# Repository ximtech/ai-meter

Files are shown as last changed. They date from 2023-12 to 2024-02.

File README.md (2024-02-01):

# AI-Meter project

#### Inspired with a project: [AI-on-the-edge-device](https://github.com/jomjol/AI-on-the-edge-device)

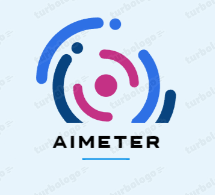
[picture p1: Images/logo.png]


## Overview

This project is a try to create a unified platform that can receive and 
handle telemetry data such as water, gas, and electricity meter readings autonomously and in an easily configurable way.

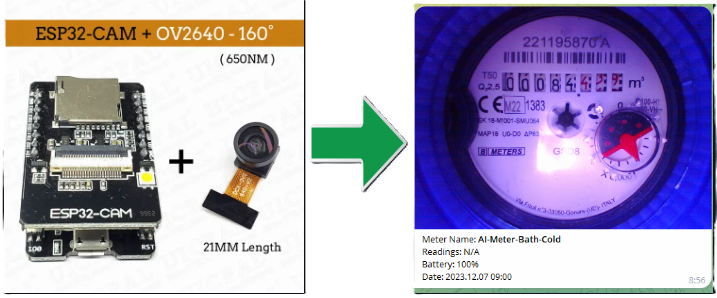
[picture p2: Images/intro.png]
esp32-cam


## Features

- Easy configuration and setup
- Modern Web View using [Bootstrap 5](https://getbootstrap.com/docs/5.0/getting-started/introduction/)
- Dynamic web pages with [Jquery](https://jquery.com/) and [CSP](https://github.com/ximtech/CSP) templates
- Telegram integration. Receive meter reading with bot support
- Flexible cron job configuration
- Timezone auto resolving using Geo IP service. Also timezone can be setup from embedded DB
- Using an advanced [Date-time](https://github.com/ximtech/GlobalDateTime) library that supports timezones and DST rules
- Embedded database(Sqlite) that stores timezones and DST rules
- Self-sufficient file server with all containing images, icons, css, js, fonts etc
- Long autonomous work from inner battery (up to 1 year)

## TODO

- Create custom ESP32 cam board with low current consumption ⬜
- File system control in an admin panel ✅
- Tensorflow Lite integration and image recognition ⬜
- Captive portal instead hardcoded IP for web view ⬜
- Wi-Fi password and other sensitive data asymmetric encryption ✅

## Table of Contents

- [How it works](#how-it-works)
  * [First time setup](#first-time-setup)
  * [Workflow](#workflow)
  * [Setup as needed](#setup-as-needed)
- [Software](#software)
  - [SD Card](#sd-card)
  - [Build](#build)
  - [Prerequisites](#prerequisites)
- [Hardware](#hardware)
  * [Adapter board](#adapter-board)
  * [Design notes](#design-notes)
  * [Power supply](#power-supply)
  * [Batteries](#batteries)
  * [External antenna](#external-antenna)
  * [Wiring](#wiring)
- [Housing](#housing)
  - [Water meter case](#water-meter-case)
    - [Assembly](#water-meter-case)
- [Geo IP](#geo-ip)
- [Telegram chat bot](#telegram-chat-bot)
- [Admin page](#admin-page)

## How it works

### First time setup

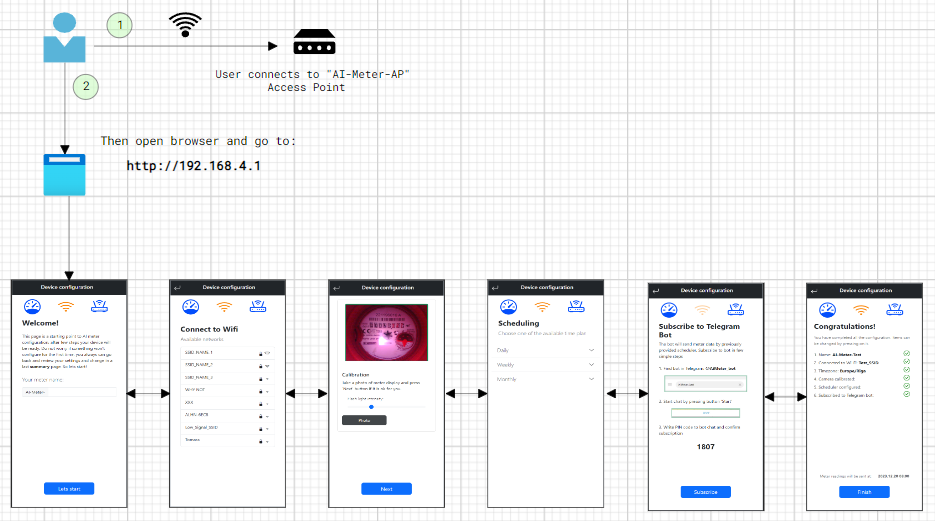
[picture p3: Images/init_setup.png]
init-setup


When `wlan.properties` is empty then a device enables access point witch user can connect and moving step by step set all required parameters.
At the last `summary.csp` page, all steps have been validated and viewed. Also, each item in the list can be changed by clicking on it.
If all ok, then 'Finish' button will be displayed, and after pressing on it, the device enables cron and go to the deep sleep. 

### Workflow

workflow

The device takes photos of a meter at a defined cron scheduler.
After initial setup, the device calculates how long need sleep;
then after wakeup it verifies if it's a time and if all ok, then starting job execution.

### Setup as needed

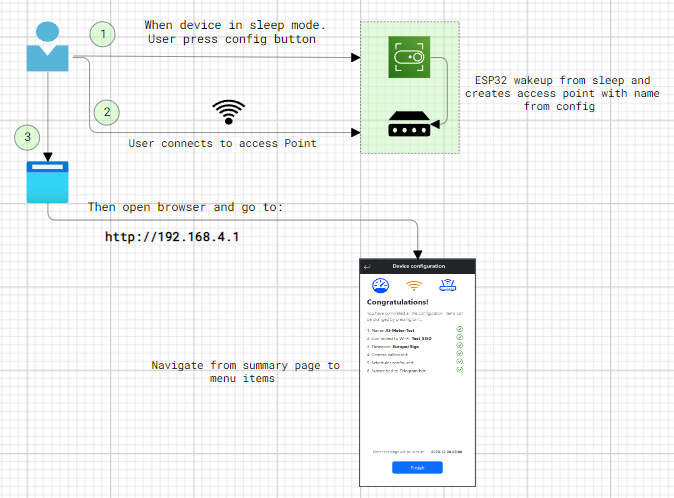
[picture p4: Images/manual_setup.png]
manual-setup


When there is a need to reconfigure or update the device while it is in sleep mode, press config button.
Then wait when led starts blinking and search Wi-Fi access point with name assigned from initial setup.

## Software

## SD Card

The software expects an SD card prepared with certain directory and file structure to work properly.
Card content can be found in `ai-meter -> MCU -> sd-card`.
Just copy all content in properly formatted(see notes) SD card.
As a result in most top directory should look like this:<br/>
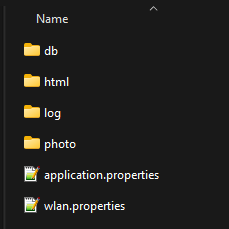
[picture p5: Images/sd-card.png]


#### Notes

- Due to the constrained GPIO availability for components such as OV2640, Flash-Light, PSRAM, and SD card,
  the communication mode with the SD card is confined to 1-line SD-Mode.
  This limitation can cause problems with high-capacity SD cards (64GB, and sometimes 32GB),
  as well as inexpensive, unbranded SD cards.
- Following setting they are necessary for formatting the SD-card: SINGLE PARTITION, MBR, FAT32—32K. NOT exFAT

#### Format example

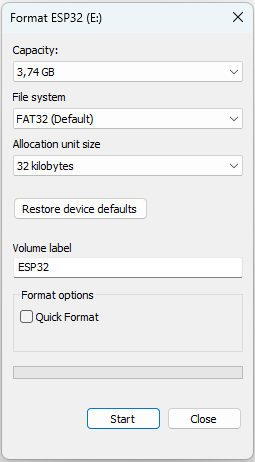
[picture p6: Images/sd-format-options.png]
format-example


### Build

### Prerequisites

- Esp-idf and Platformio should be already installed

The most common way to get firmware is to build it from sources:
- Clone this repository and open `MCU` directory as a project:
- In `Visual Studio Code` -> Open Folder -> MCU
- Then run PlatformIO build: <br/>
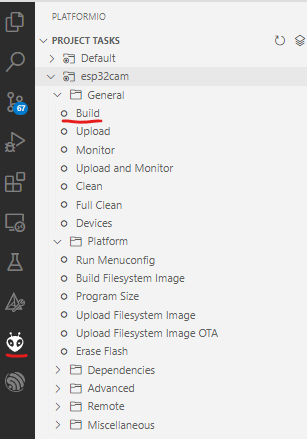
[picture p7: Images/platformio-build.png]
platformio-build
  
- If all ok, plug the device:<br/>
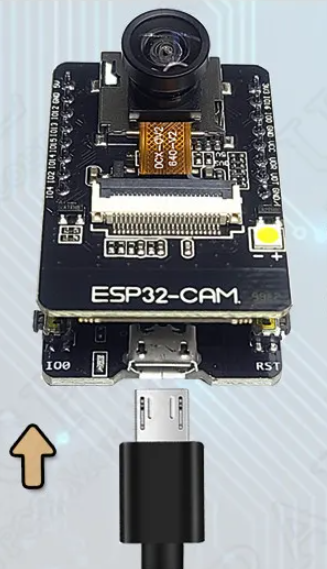
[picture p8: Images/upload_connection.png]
upload_connection_2
  
- Then upload firmware
- When the process is finished, turn on the monitor to see log outputs:<br/>
  battery
- By default, console log enabled and `debug` level is set (can be changed in config)

## Hardware

- ESP32 CAM Camera Module Kit
- OV2640 Camera Module, 120 or 160 Degree, 2MP
- External 4 or 8 MB PSRAM
- Micro SD card from 2 to 8 GB
- USB download board
- Battery power supply, adapter board (see below)

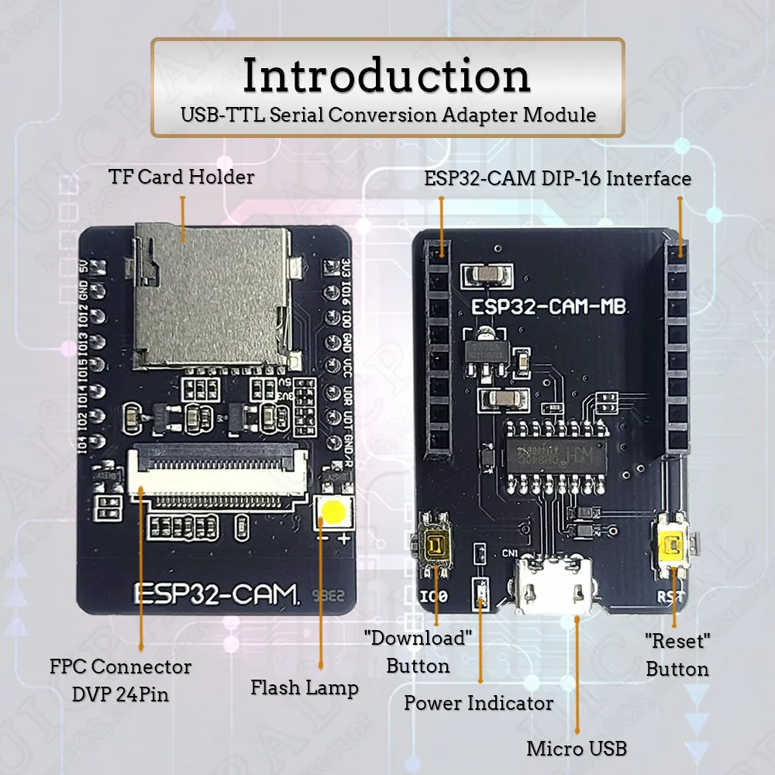
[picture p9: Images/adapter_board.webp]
adapter-board


### Adapter board

ESP32 module kit does not support to be powered from batteries by default.
So to use the device autonomously without an external power supply, there is a need to update `USB download board`
to a custom solution.
The directory `esp32-cam-shield` is an Altium project that contains all sources for this board.

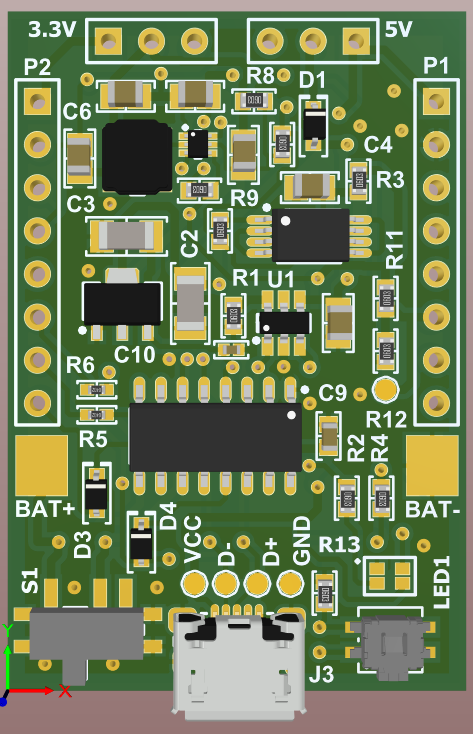
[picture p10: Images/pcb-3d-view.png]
pcb-3d-view


The PCB contains: 
- Almost all parts from the original `USB download board`
- Li-ion charger
- Battery protection
- Step-down converter

Altium project also already contains prepared fabrication files (gerber files, NC drill etc.) in one archive `esp32-cam-shield.rar`
Just place it, for example, in jlcpcb quote as follows:

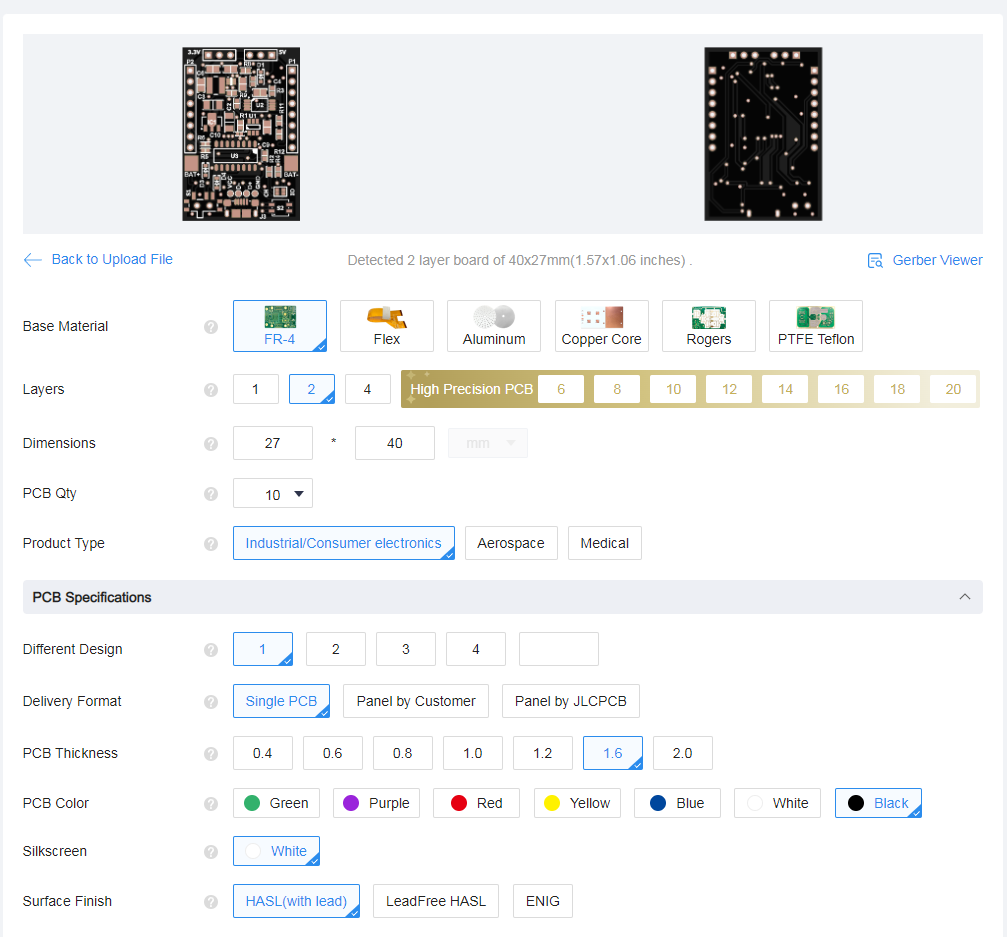
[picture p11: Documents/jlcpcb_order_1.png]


More info (schematic, PCB, BOM etc.) in `esp32-cam-shield` project

### Design notes

- For current housing, push button and switch should be used as follows:<br/>
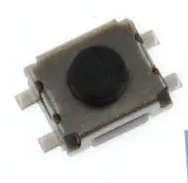
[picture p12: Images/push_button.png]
push-button
<br/>

#### 3x4x2 mm SMD Switch 4 Pin Micro Switch Push Button

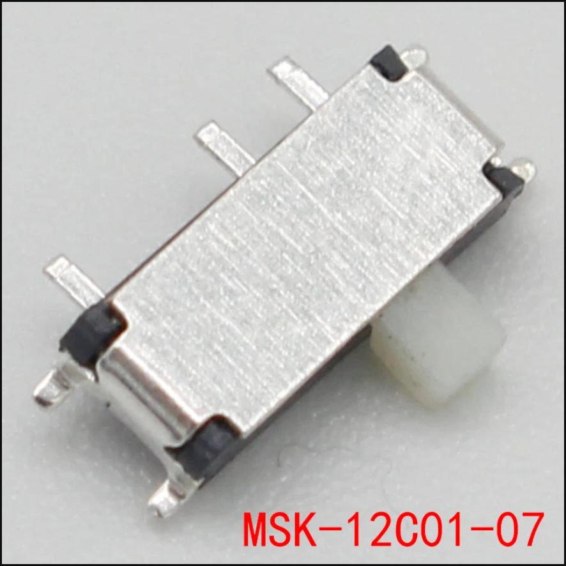
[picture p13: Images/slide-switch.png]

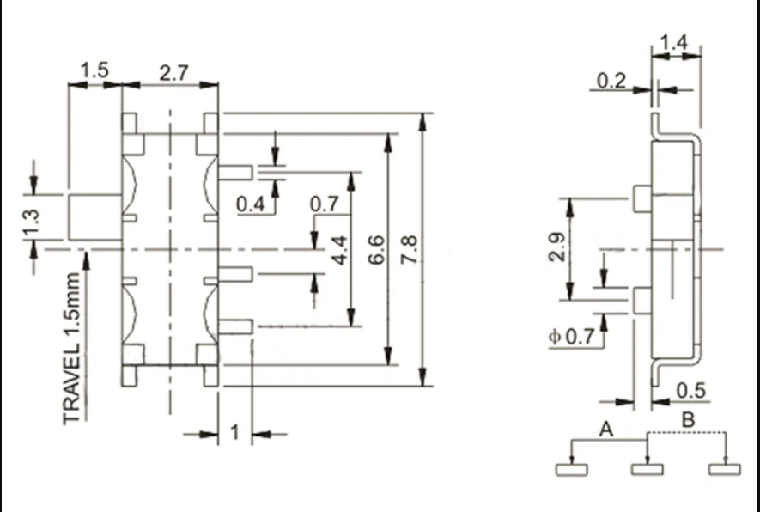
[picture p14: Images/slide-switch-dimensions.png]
<br/>

#### Mini Slide Switch On-OFF 2 positions, 7 pins

### Power supply

With the adapter board, there are two types of power supply available: 
- External 5V via USB and should support minimum 500mA. Solder two pins together to switch external power supply:<br/>
push-button
- From inner li-ion battery, also can be charged from USB. Solder this pins:<br/>
push-button

### Batteries

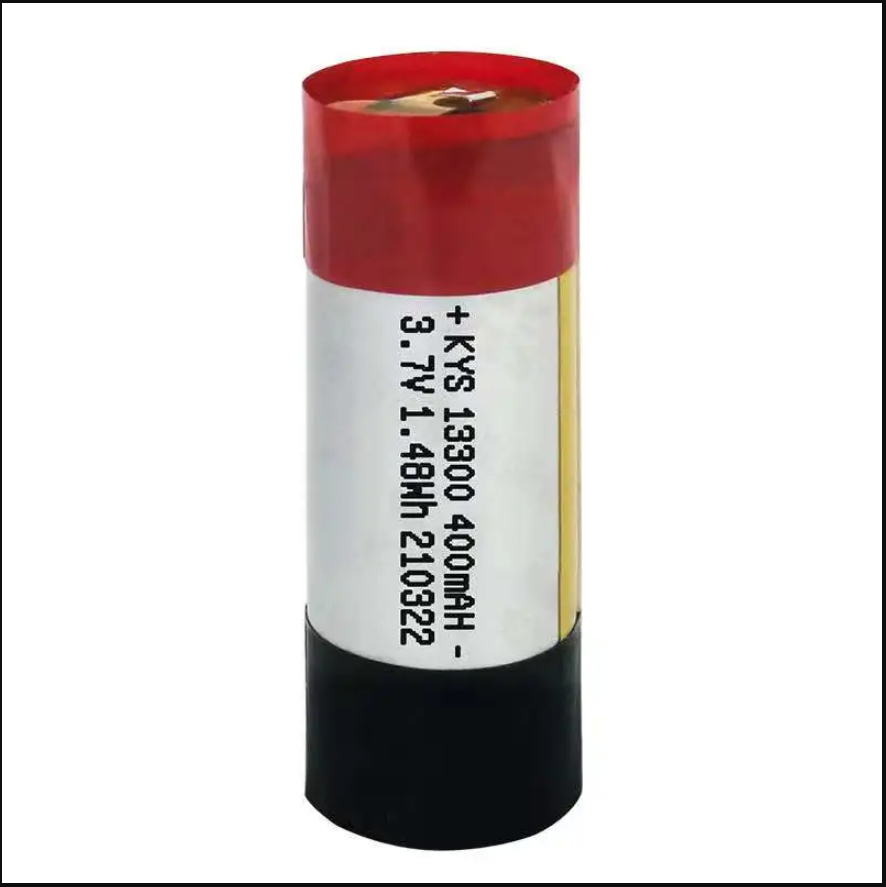
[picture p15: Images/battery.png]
battery


- Type: 13300
- Size: 13mm x 30mm
- Li-ion 3.7V 400mAh
- Count: 3

Such batteries are widely used at one-time vapes and can be extracted from used electronic smoke.

### External antenna

***Optional***, but highly recommended to use external antenna,
because using an external antenna can solve problems related to connectivity problems and speed up data transmission.

- Take a look at your board to see if it is set to use the on-board antenna or the IPEX connector.<br/>
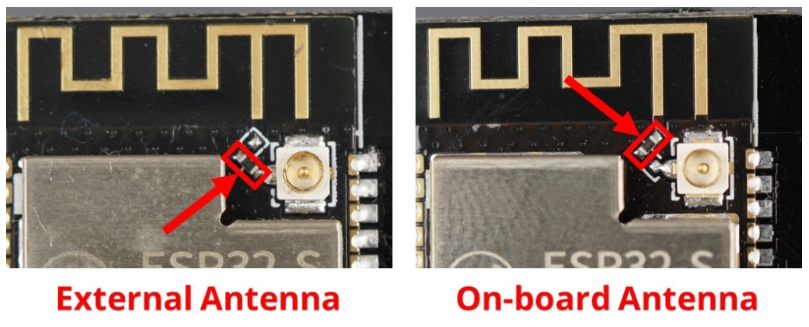
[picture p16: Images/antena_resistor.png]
antenna-resistor

- To enable or disable the on-board antenna, you just need to unsolder that resistor and solder it in the desired configuration. 
You can also drop some solder to connect those points (you don’t necessarily need to add the resistor as long as the pads are connected)
- Next, there is a need to connect flexible patch antenna with cable length about 10 cm:<br/>
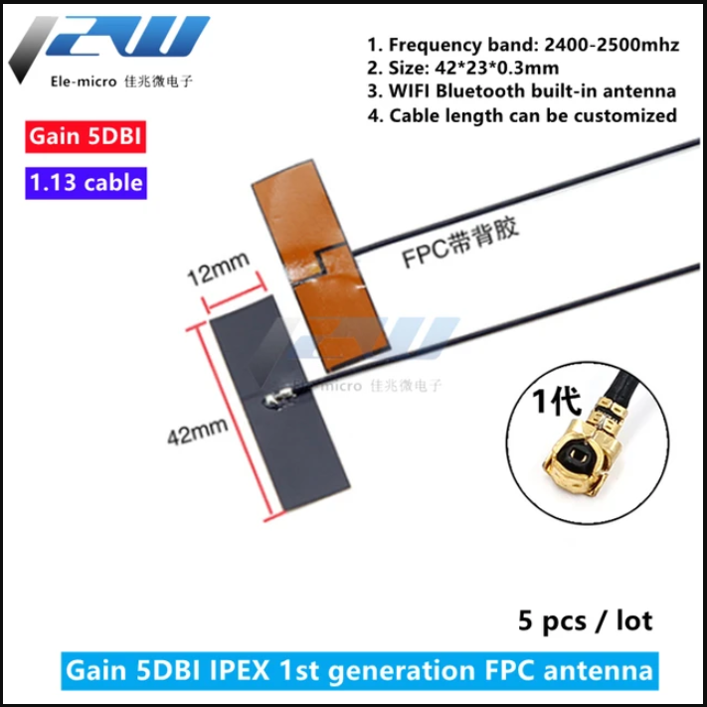
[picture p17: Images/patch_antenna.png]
antenna-resistor


## Wiring

After soldering all together, it should look like on a photo:<br/>
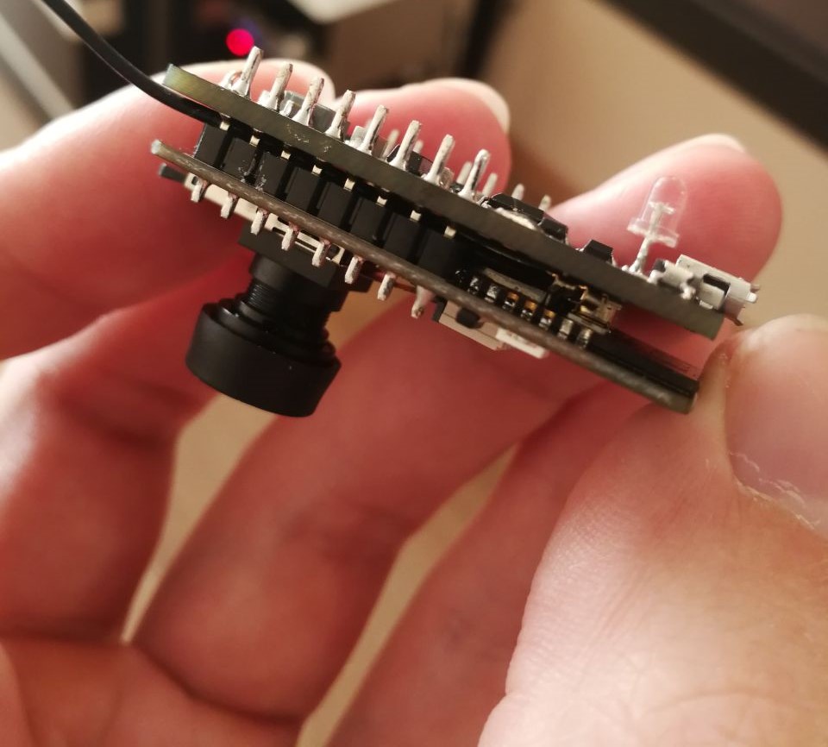
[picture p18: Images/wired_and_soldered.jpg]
wired-and-soldered
<br/>

## Housing

---

## Water meter case

The `3D Model` directory contains `SolidWorks` source models for 3D printing.
All that needs to be printed for a single device from `water` directory:
- 1x -`Base.SLDASM` -> ***Resolution: 0.2, Walls: 2–3, Infill: 20%+, Supports: Yes, Filament material: PLA***
- 3x -`Battery_Lid.SLDASM` -> ***Resolution: 0.2, Walls: 2, Infill: 100%, Supports: No, Filament material: PLA***
- 1x -`Button.SLDASM` -> ***Resolution: 0.12, Walls: 2, Infill: 100%, Supports: No, Filament material: PLA***
- 1x -`Flash_Reflector.SLDASM` -> ***Resolution: 0.12, Walls: 2, Infill: 50%+, Supports: No, Filament material: Transparent PLA***
- 1x -`Led_Pipe.SLDASM` -> ***Resolution: 0.12, Walls: 2, Infill: 100%, Supports: No, Filament material: Transparent PLA***
- 1x -`Holder.SLDASM` -> ***Resolution: 0.2, Walls: 2–3, Infill: 20%+, Supports: No, Filament material: PLA***
- 1x -`Lid.SLDASM` -> ***Resolution: 0.2, Walls: 2–3, Infill: 20%+, Supports: No, Filament material: PLA***
- 1x -`On_Off_Switch.SLDASM` -> ***Resolution: 0.12, Walls: 2, Infill: 100%, Supports: No, Filament material: PLA***

## Assembly

### Prerequisites

- 4x - ***M3 Brass inserts: 5–8mm tall***
- 20x - ***3x2mm Round neodymium magnets***<br/>
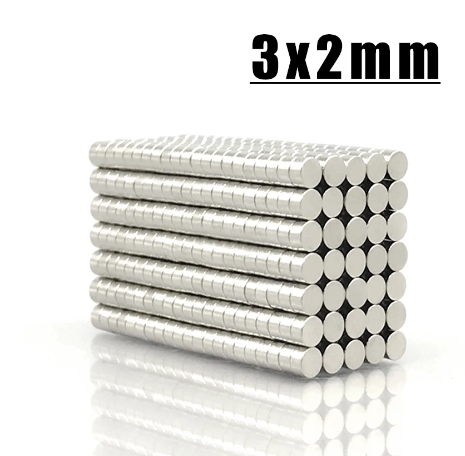
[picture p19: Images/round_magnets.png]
round-magnets


### 1. Melt brass inserts into the base holes

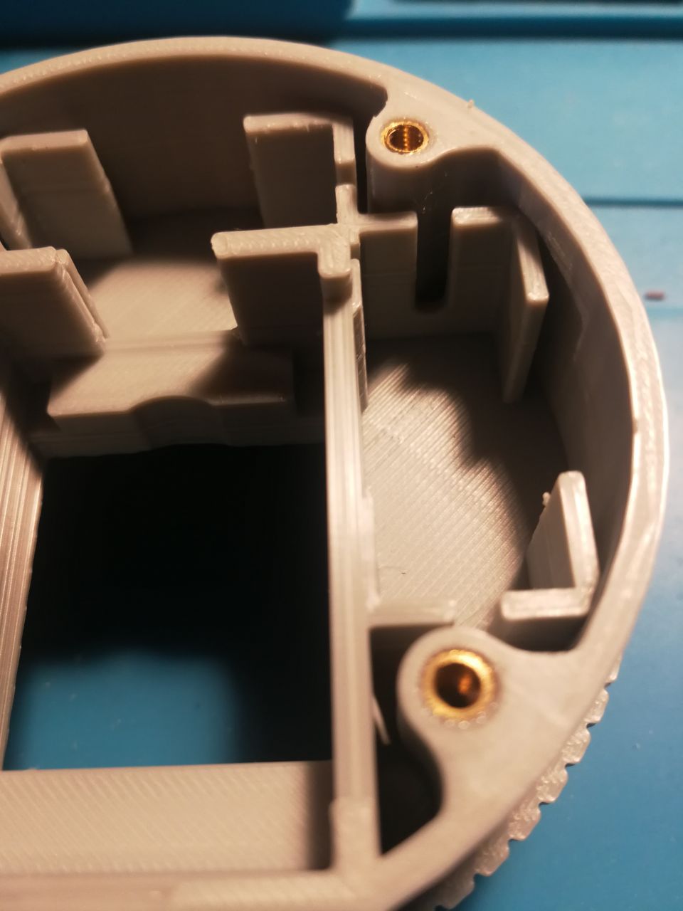
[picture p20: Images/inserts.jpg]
inserts


### 2. Insert contact magnets to base and holder

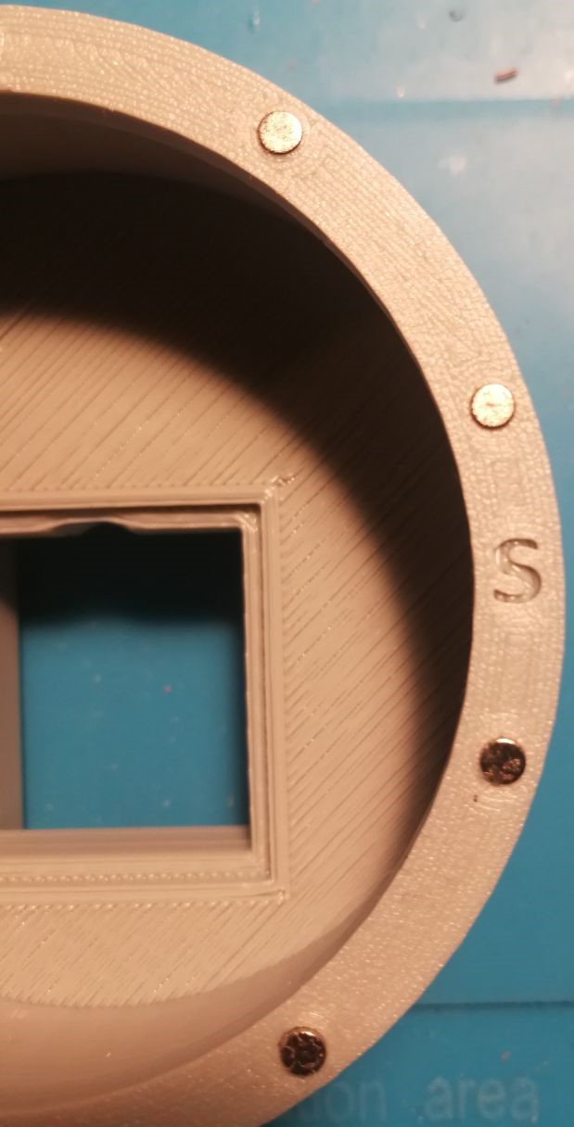
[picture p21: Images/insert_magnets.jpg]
magnets


***Note:*** Place magnets according to a letter on the case: `S` -> indicating that the south pole should be facing upward. 

### 3. Place reflector

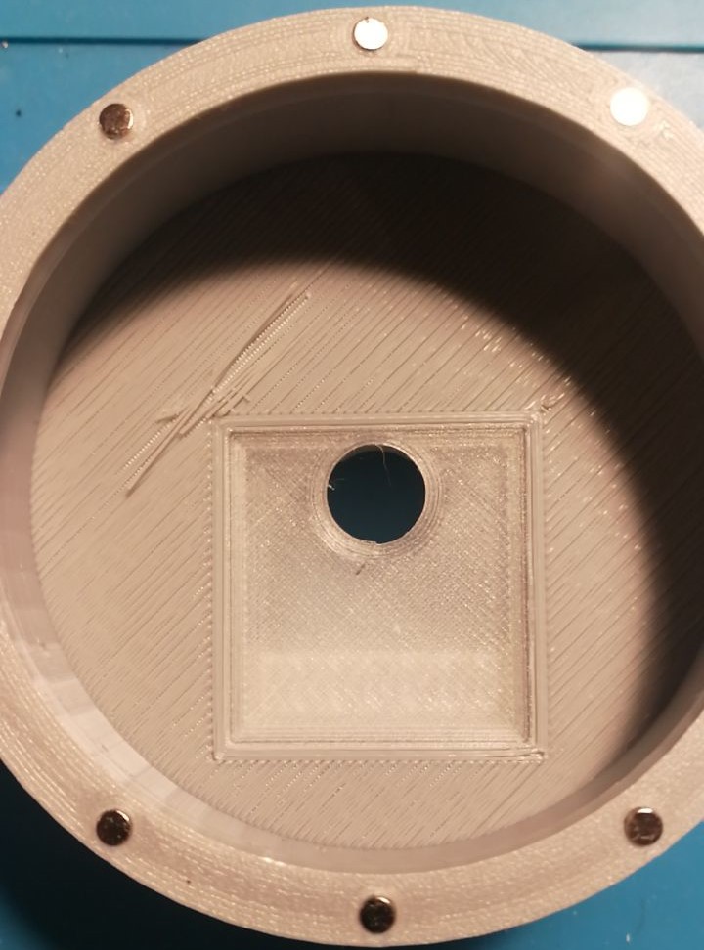
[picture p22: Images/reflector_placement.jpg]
reflector


### 4. Place and then solder battery wires

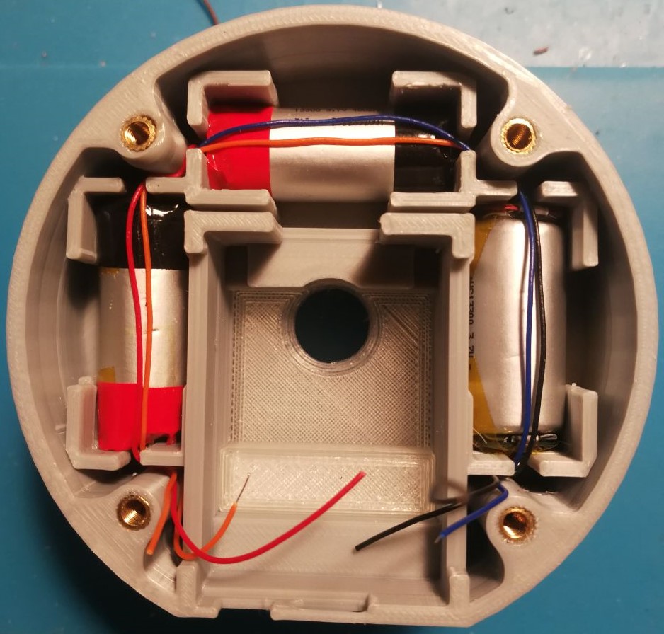
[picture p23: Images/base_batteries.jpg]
batteries


***Note: Connect all batteries in parallel***

### 5. Cover batteries

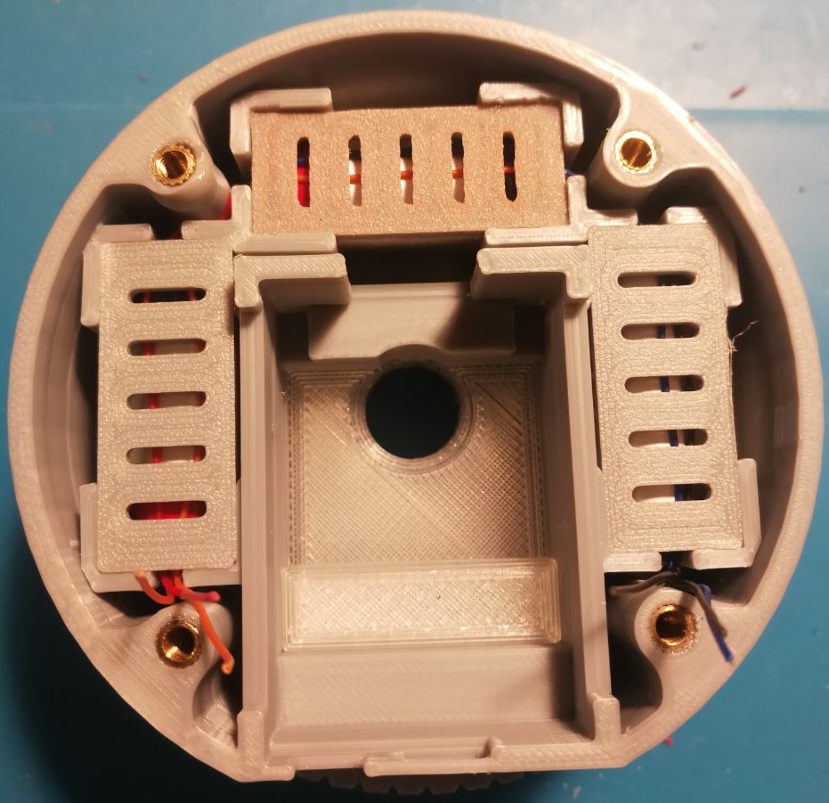
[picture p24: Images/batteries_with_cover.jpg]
batteries_with_cover


### 6. Place PCB

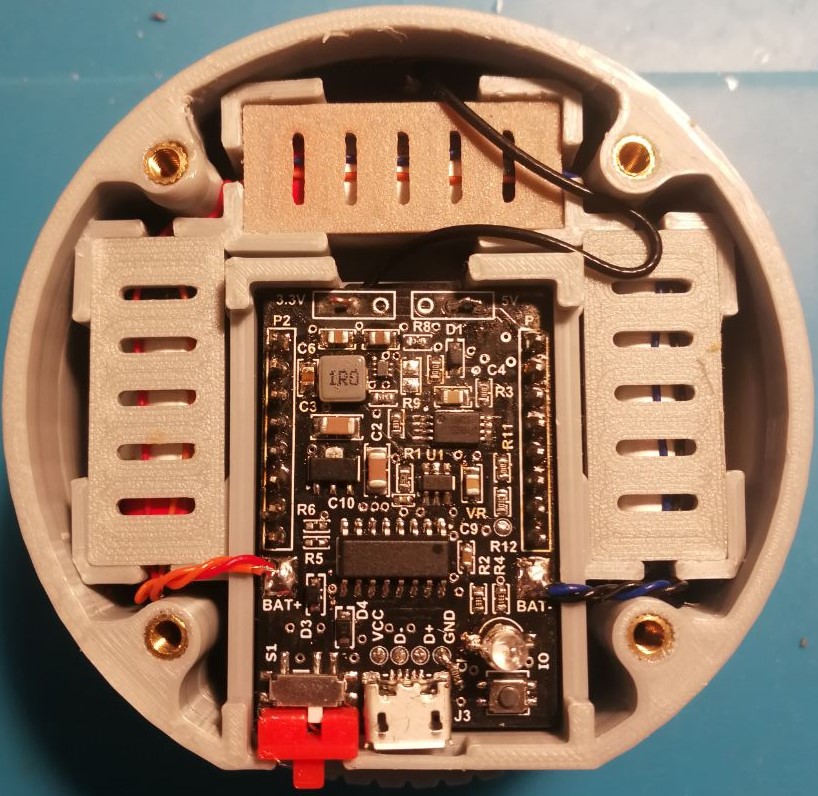
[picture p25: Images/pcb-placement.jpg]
pcb-placement


### 7. Place on/off switch, button and led pipe

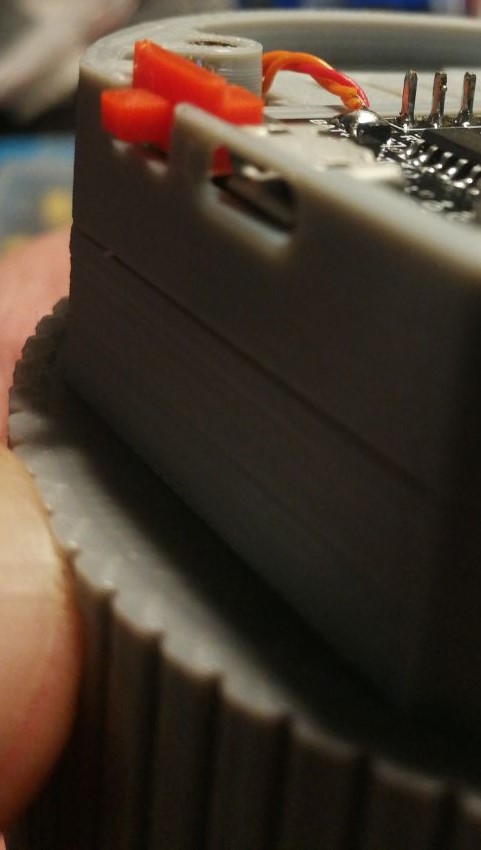
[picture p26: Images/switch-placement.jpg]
switch-placement

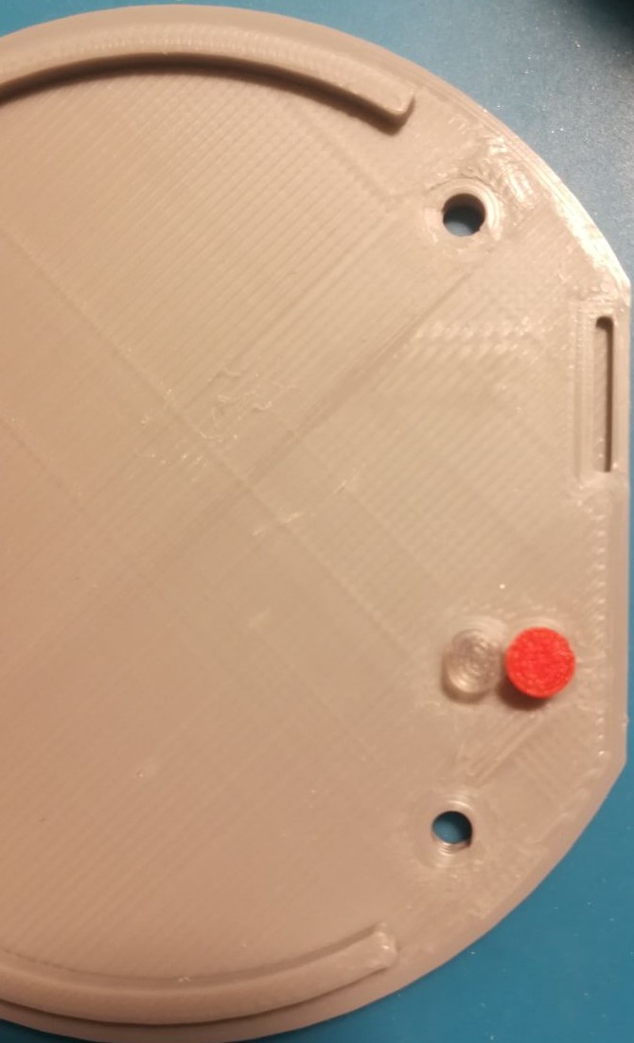
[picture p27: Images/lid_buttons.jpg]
lid_buttons


### 8. Screw up the lid

### 9. Mounting

---

## Geo IP

Register and get IP geolocation API token: [link](https://ipgeolocation.io/)

## Telegram chat bot

How to create a Telegram bot: [link](https://www.directual.com/lesson-library/how-to-create-a-telegram-bot)

## Admin page

Access the admin page through the following link: `http://192.168.4.1/admin`<br/>
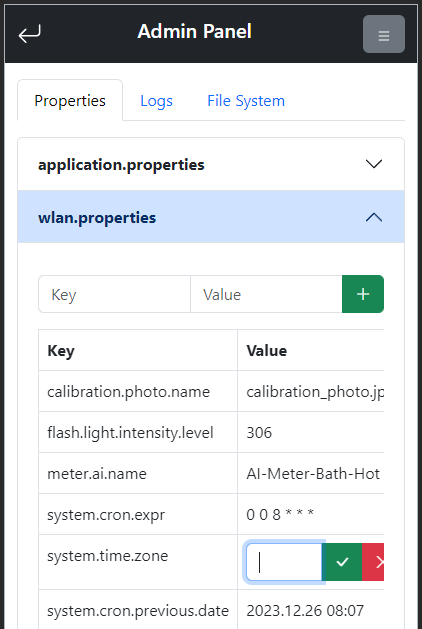
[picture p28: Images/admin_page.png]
<br/>

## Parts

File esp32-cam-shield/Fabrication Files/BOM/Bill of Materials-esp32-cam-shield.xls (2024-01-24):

Quantity | Designator | Comment | Footprint
1 | C1 | 2.2 µF | CAP 0805_2012
2 | C2, C3 | 10 µF | CAP 1206_3216 - 0.8MM
1 | C4 | 0.1 µF | CAP 0805_2012
1 | C5 | 120 pF | CAP 0805_2012
2 | C6, C7 | 22 µF | CAP 0805_2012
1 | C8 | 4.7 µF | CAP 0805_2012
1 | C9 | 0.1 µF | CAP 0603_1608
1 | C10 | 120pF | CAP 0402_1005
3 | D1, D3, D4 | 1N4148WS-HG3-08 | SOD323
5 | D-, D+, GND, TP10, VCC | Test point | TEST_POINT
1 | IC1 | PJ6206A | ON SEMI SOT-89 H
1 | J3 | 10118193-0001LF | FCI USB 10118193-0001LF
1 | L1 | 15 µH | TAIYO YUDEN NR4018
1 | LED1 | Bicolor 1615 | LED 0603 1615 BICOLOR
2 | P1, P2 | Header 8 | HDR1X8
2 | P3, P4 | Header 3 | HDR1X3
1 | R1 | 3.9 kOhms | RES 0603_1608
2 | R2, R4 | 330 Ohms | RES 0603_1608
1 | R3 | 100 Ohms | RES 0603_1608
2 | R5, R6 | 0 Ohms | RES 0402_1005
2 | R7, R11 | 100 kOhms | RES 0603_1608
1 | R8 | 453 kOhms | RES 0603_1608
1 | R9 | 1 kOhms | RES 0603_1608
1 | R10 | 499 kOhms | RES 0603_1608
1 | R12 | 10 kOhms | RES 0603_1608
1 | R13 | 5 kOhms | RES 0603_1608
1 | S1 | Mini Slide Switch | MINI SLIDE SWITCH
1 | S2 | EVQ-P7A01P | EVQ-P7A01P
1 | U1 | TP4057 | TI SOT-23-6 DDC
1 | U2 | DW03D | TI MSOP-8 DGS
1 | U3 | CH340G | TI SOP-16 D
1 | U4 | TPS62A01ADRLR | TI SOT-563 DRL

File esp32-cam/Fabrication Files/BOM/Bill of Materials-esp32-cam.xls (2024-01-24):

Quantity | Designator | Comment | Footprint
6 | C1, C3, C4, C5, C7, C14 | 0.1 µF | CAP 0805_2012
1 | C2 | 15 pF | CAP 0805_2012
4 | C6, C9, C11, C13 | 10 µF | CAP 0805_2012
2 | C8, C10 | 100 µF | CAP POL 1411_3528
1 | C12 | 1 µF | CAP 0805_2012
1 | D1 | LED MID PWR 5600K 95CRI 3030 | LUMINUS MP-3030-110
1 | IC1 | ESP-32S | ESP32s
1 | IC2 | Si2301DS | DIODES SOT-23-3
2 | IC3, IC5 | XC6206 | TI SOT-23-3 DBZ
1 | IC4 | ESP-PSRAM64H | ALPHAOMEGA SO8 SOP-8L
1 | J1 | OV2640 FPC 24pin | GCT FFC2B28-24
1 | J2 | Micro SD Socket | OOTDTY Y98E7HH800293
2 | P1, P2 | Header 8 | HDR1X8
1 | Q1 | S8050 SOT-23-3 | MCCSEMI SOT-23-3
4 | R1, R2, R3, R7 | 4.7 kOhms | RES 0603_1608
2 | R4, R15 | 1 kOhms | RES 0603_1608
5 | R5, R6, R12, R14, R16 | 10 kOhms | RES 0603_1608
4 | R8, R9, R10, R13 | 47 kOhms | RES 0603_1608
1 | R11 | NC | RES 0603_1608
1 | S1 | EVQ-P7A01P | EVQ-P7A01P
5 | TP1, TP2, TP3, TP4, TP5 | Test point | TEST_POINT

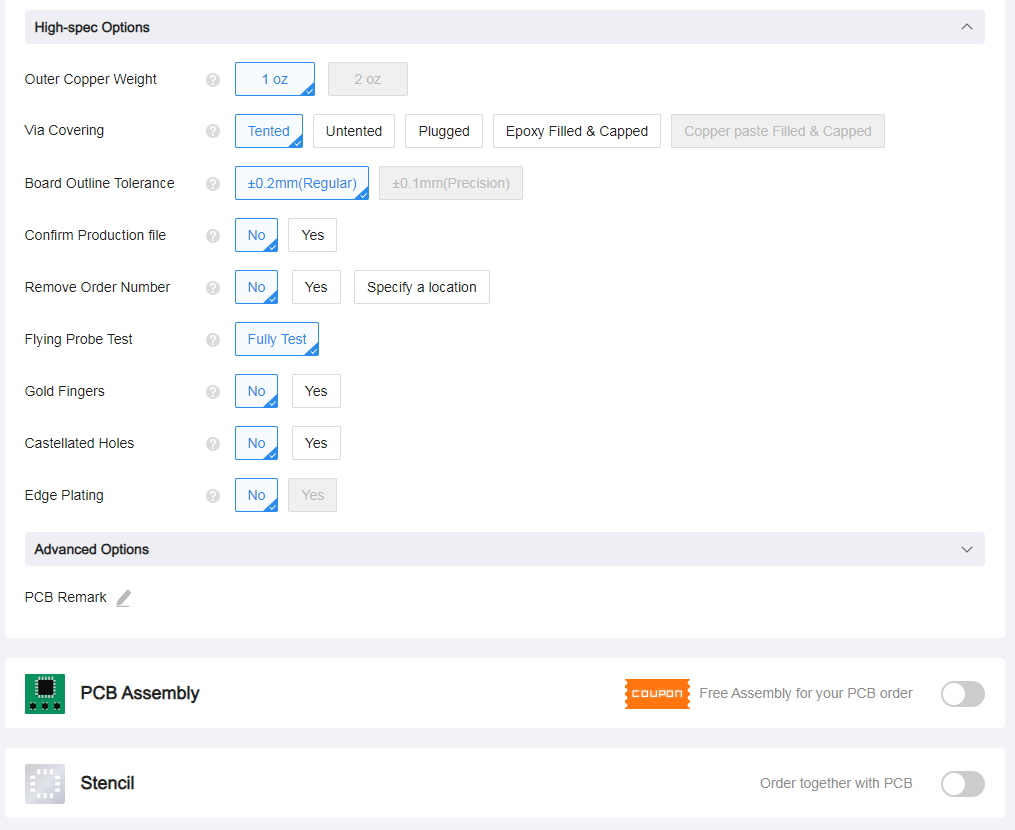
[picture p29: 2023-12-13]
Documents/jlcpcb_order_2.png

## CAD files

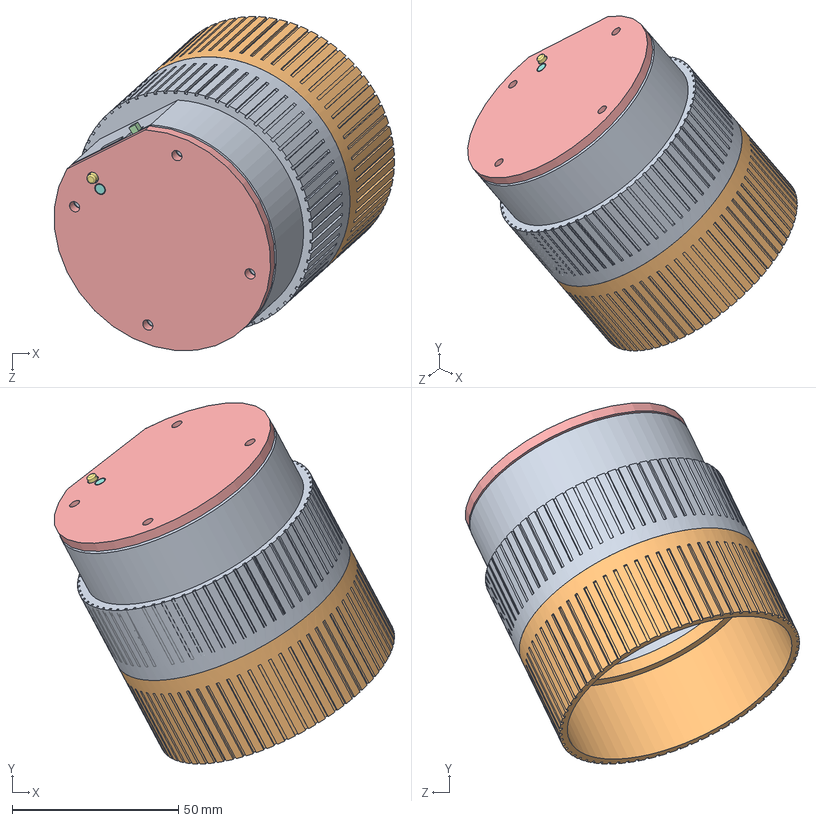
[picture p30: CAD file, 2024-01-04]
3D Model/water/Assembly.SLDASM
102.4 x 108.7 x 100.6 mm
Base
Holder
Flash_Reflector
On_Off_Switch
Lid
Battery_Lid x 3
Button
Led_Pipe

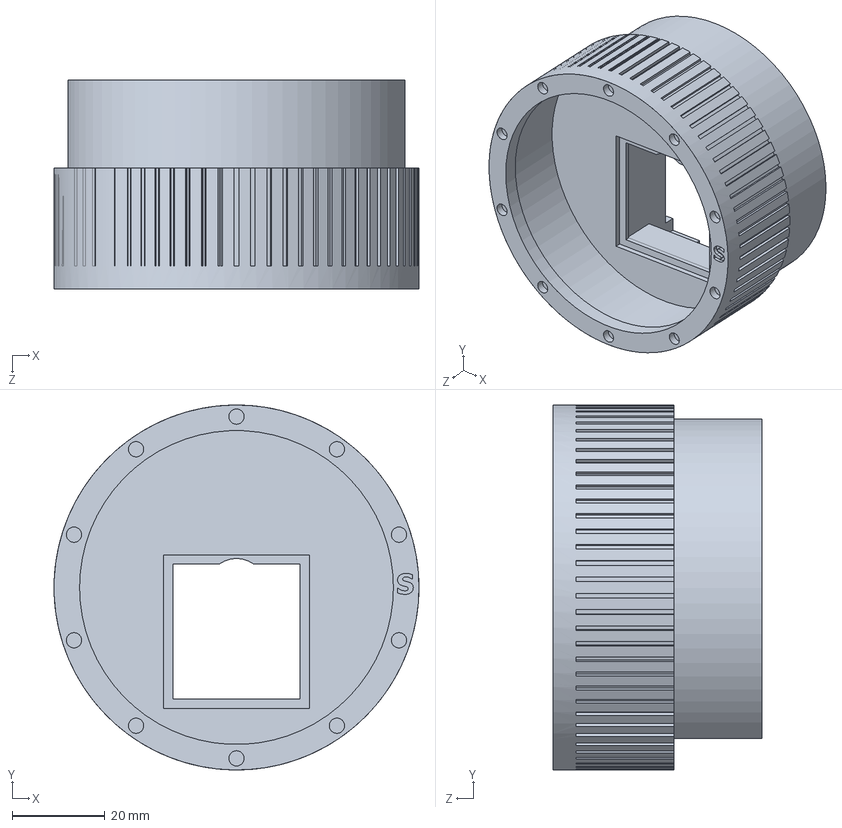
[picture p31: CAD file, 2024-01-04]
3D Model/water/Base.SLDPRT
78.5 x 78.5 x 45.0 mm

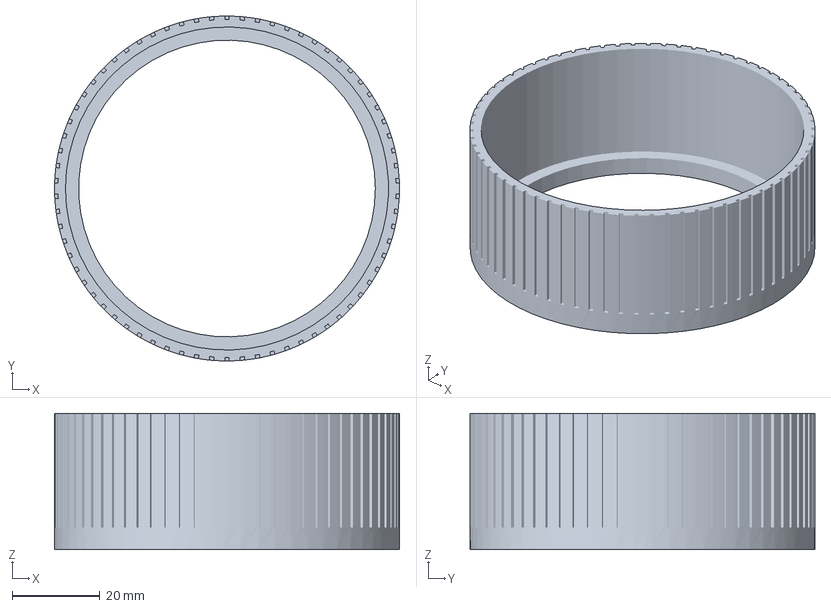
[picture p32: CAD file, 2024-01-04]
3D Model/water/cura-project/Meter_Holder.3mf
78.5 x 78.5 x 31.0 mm

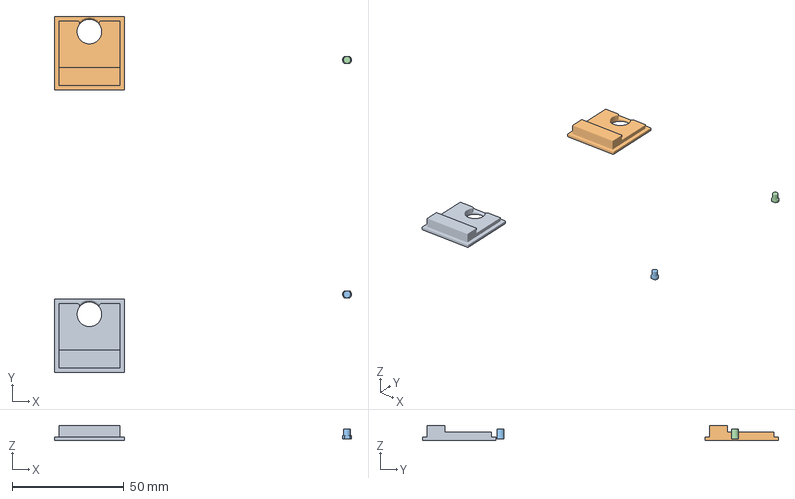
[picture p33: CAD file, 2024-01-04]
3D Model/water/cura-project/Meter_FRef_Led_2x.3mf
132.6 x 159.0 x 6.70 mm
Flash_Reflector.SLDPRT
Flash_Reflector.SLDPRT(1)
Led_Pipe.SLDPRT
Led_Pipe.SLDPRT(1)

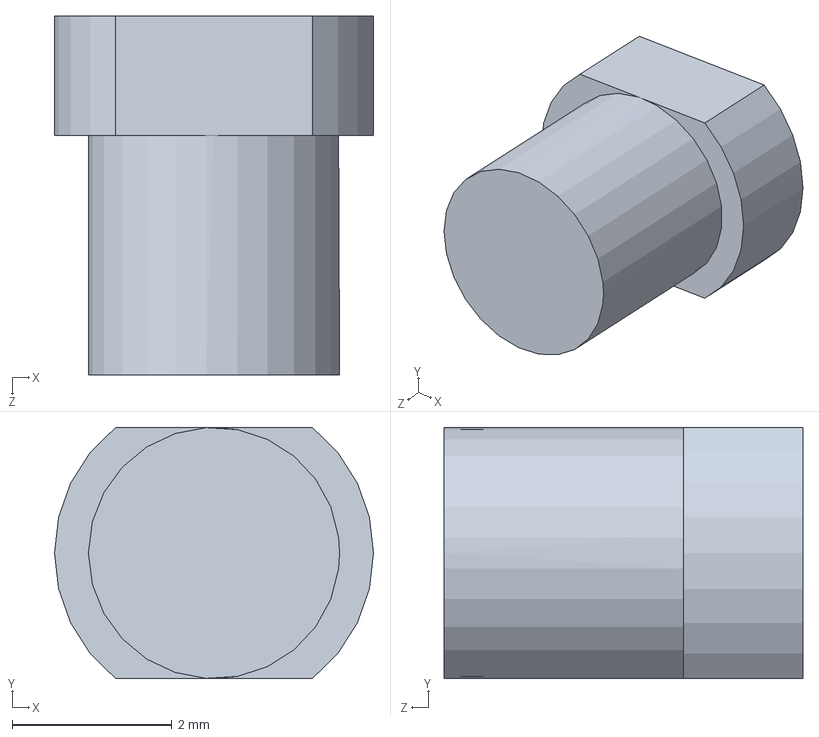
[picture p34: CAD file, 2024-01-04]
3D Model/water/Led_Pipe.SLDPRT
4.00 x 3.15 x 4.50 mm

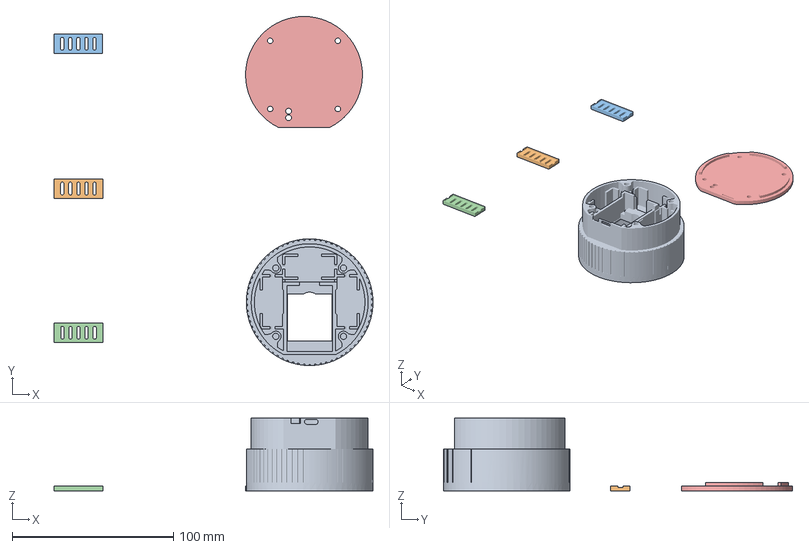
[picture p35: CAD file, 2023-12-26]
3D Model/water/cura-project/Meter-Base_Lid_BLid.3mf
197.7 x 216.3 x 45.0 mm
Base.SLDPRT
Battery_Lid.SLDPRT
Battery_Lid.SLDPRT(1)
Battery_Lid.SLDPRT(2)
Lid.SLDPRT

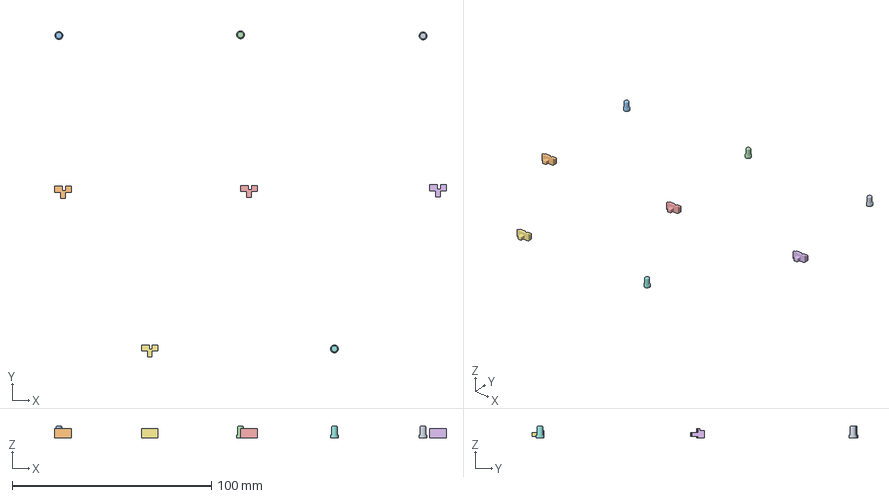
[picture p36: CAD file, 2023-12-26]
3D Model/water/cura-project/Meter_Butt_Sw_4x.3mf
196.8 x 163.8 x 6.00 mm
Button.SLDPRT
On_Off_Switch.SLDPRT
Button.SLDPRT(1)
Button.SLDPRT(2)
On_Off_Switch.SLDPRT(1)
On_Off_Switch.SLDPRT(2)
On_Off_Switch.SLDPRT(3)
Button.SLDPRT(3)

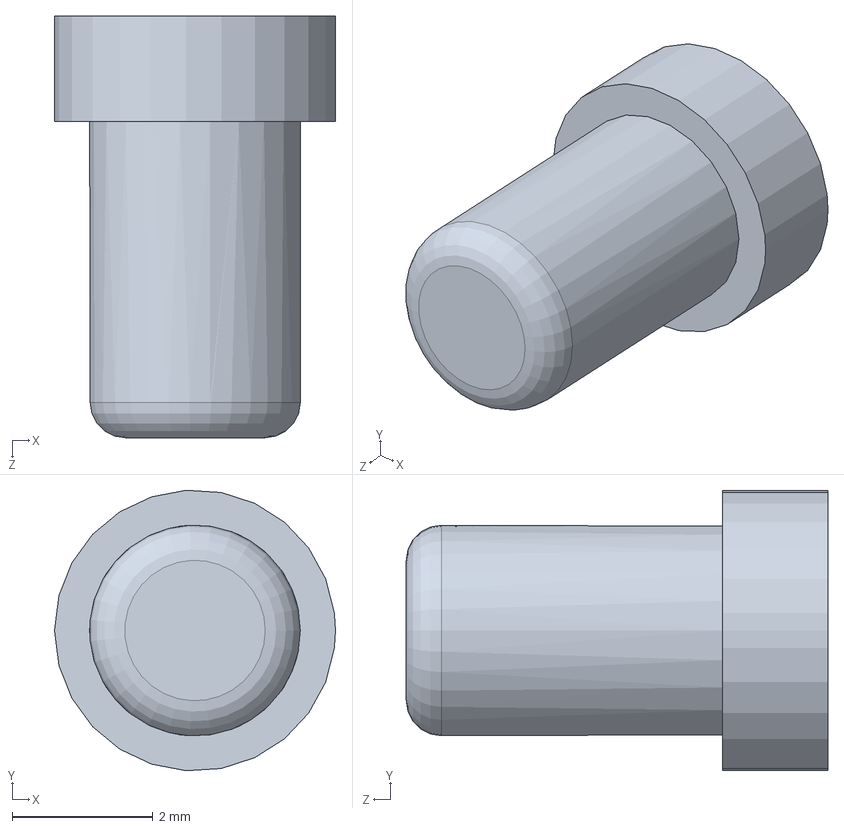
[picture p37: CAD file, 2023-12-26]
3D Model/water/Button.SLDPRT
4.00 x 3.99 x 6.00 mm

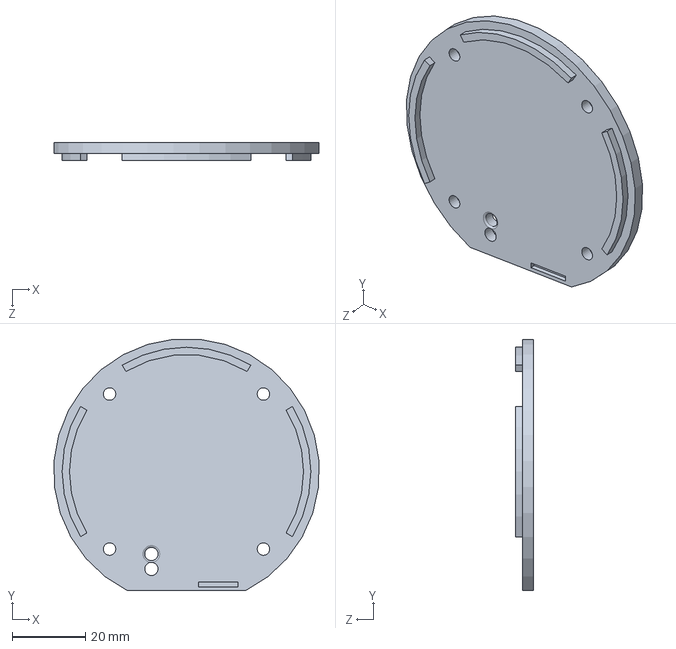
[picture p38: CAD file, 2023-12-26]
3D Model/water/Lid.SLDPRT
72.2 x 68.5 x 5.00 mm

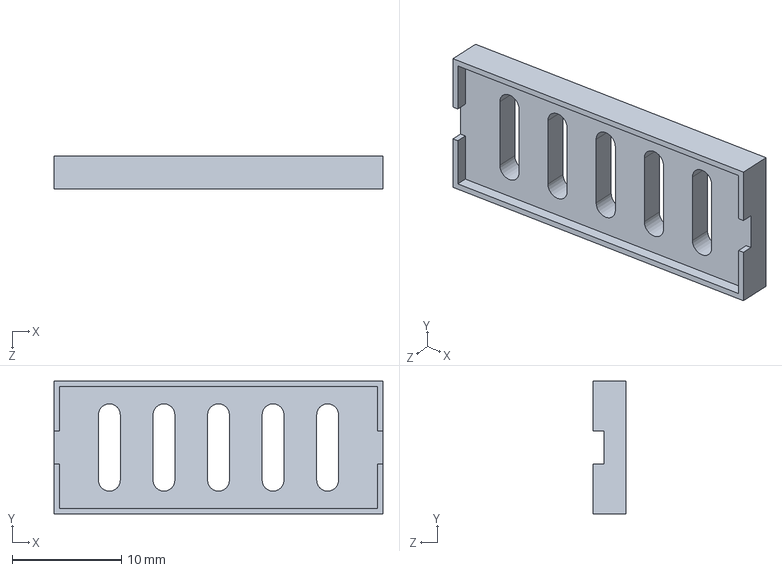
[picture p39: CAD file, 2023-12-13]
3D Model/water/Battery_Lid.SLDPRT
30.1 x 12.1 x 3.00 mm

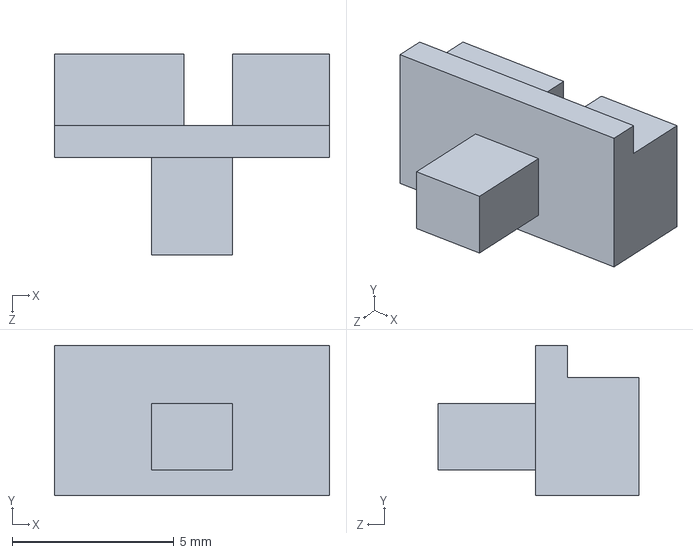
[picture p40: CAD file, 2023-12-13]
3D Model/water/On_Off_Switch.SLDPRT
8.50 x 4.65 x 6.20 mm

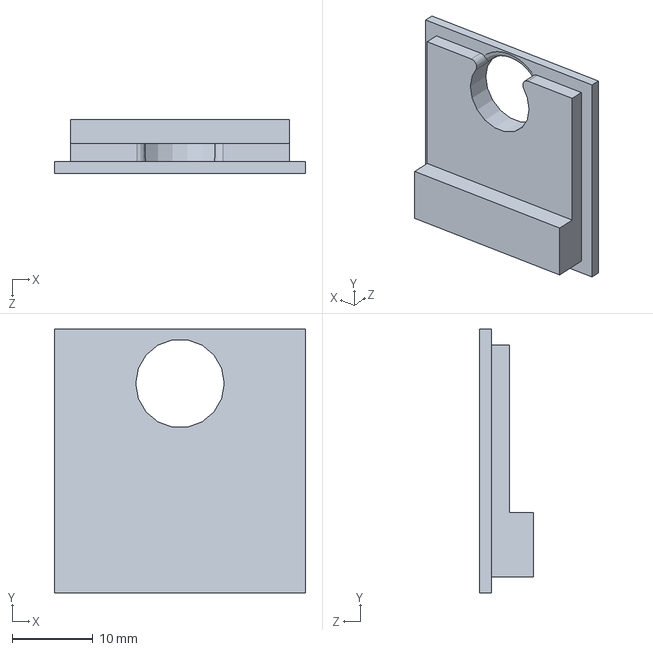
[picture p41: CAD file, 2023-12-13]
3D Model/water/Flash_Reflector.SLDPRT
31.2 x 32.8 x 6.70 mm

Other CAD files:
3D Model/water/Holder.SLDPRT

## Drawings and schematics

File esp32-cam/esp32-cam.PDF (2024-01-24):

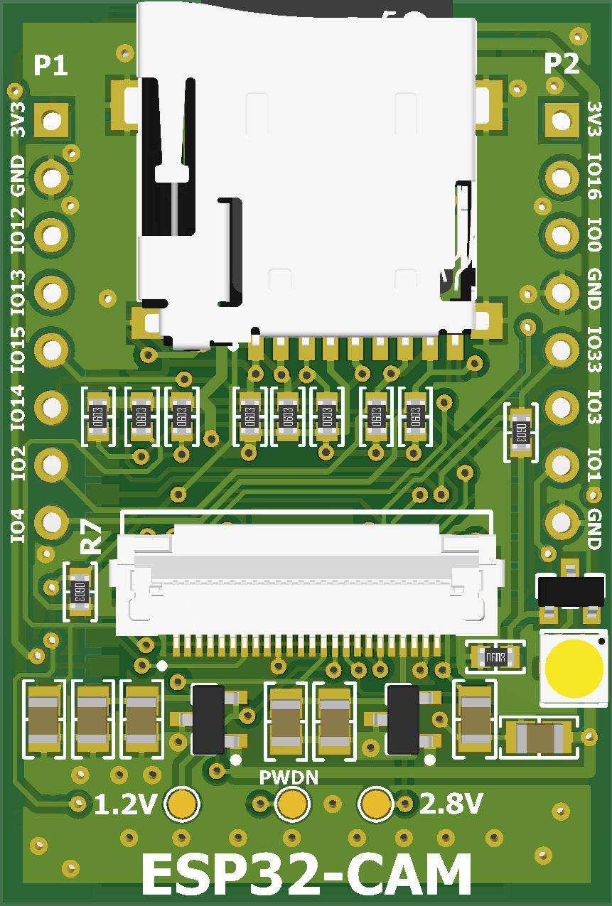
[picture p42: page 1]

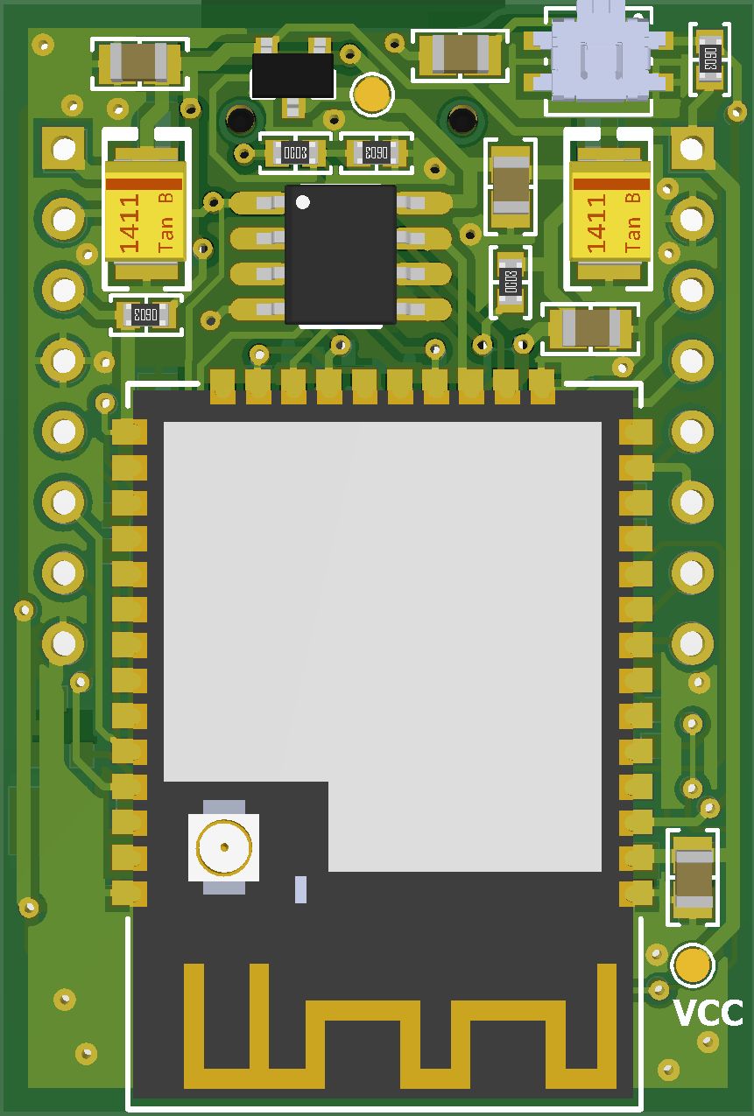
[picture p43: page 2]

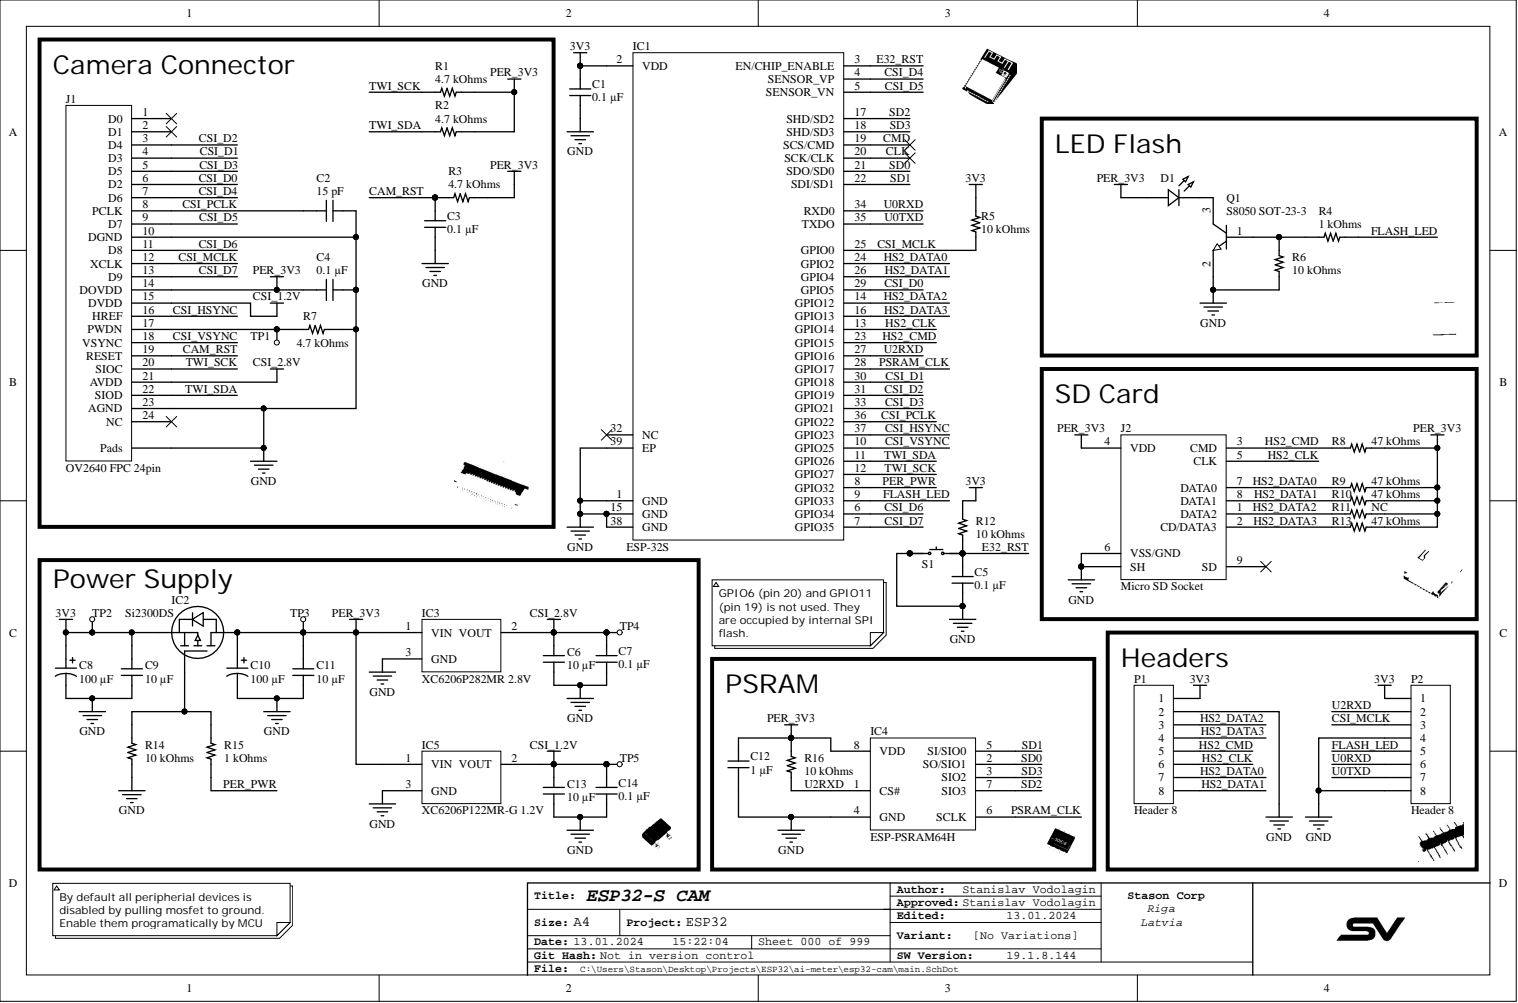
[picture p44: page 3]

GPIO6 (pin 20) and GPIO11
(pin 19) is not used. They
are occupied by internal SPI
flash.
PSRAM

By default all peripherial devices is
disabled by pulling mosfet to ground.
Enable them programatically by MCU

Approved: Stanislav Vodolagin

Size: A4 | Project: ESP32 | Edited: 13.01.2024

Variant: [No Variations]

Date: 13.01.2024 15:22:04 | Sheet 000 of 999
Git Hash: Not in version control | | SW Version: 19.1.8.144
File: C:\Users\Stason\Desktop\Projects\ESP32\ai-meter\esp32-cam\main.SchDot

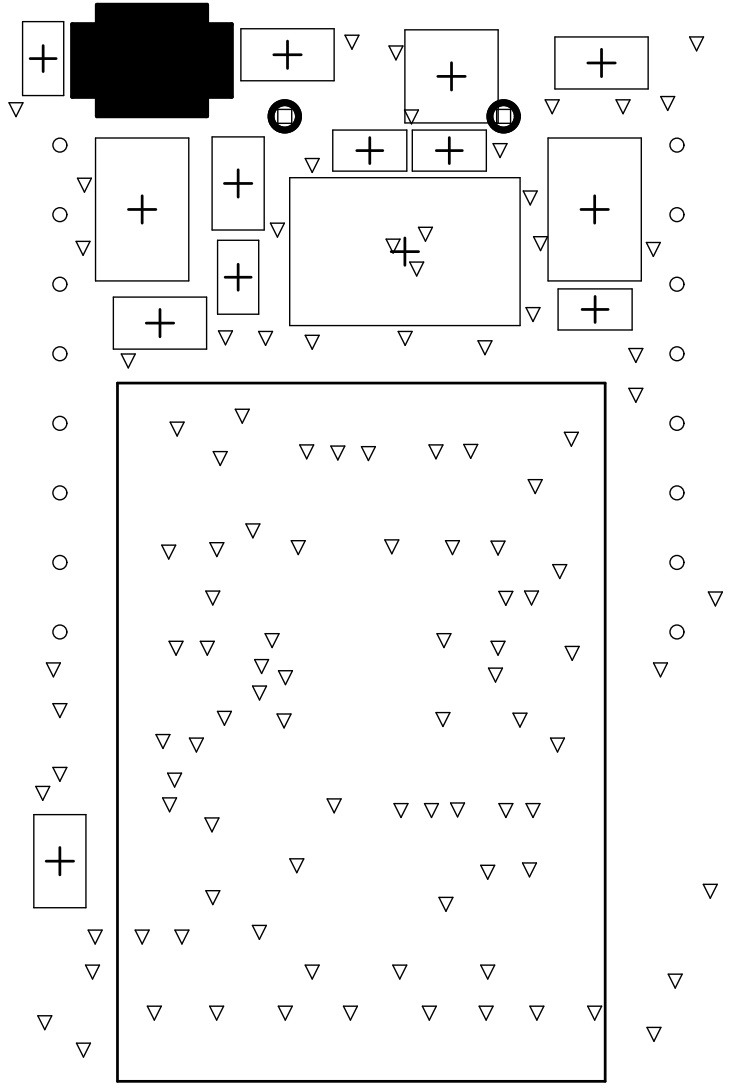
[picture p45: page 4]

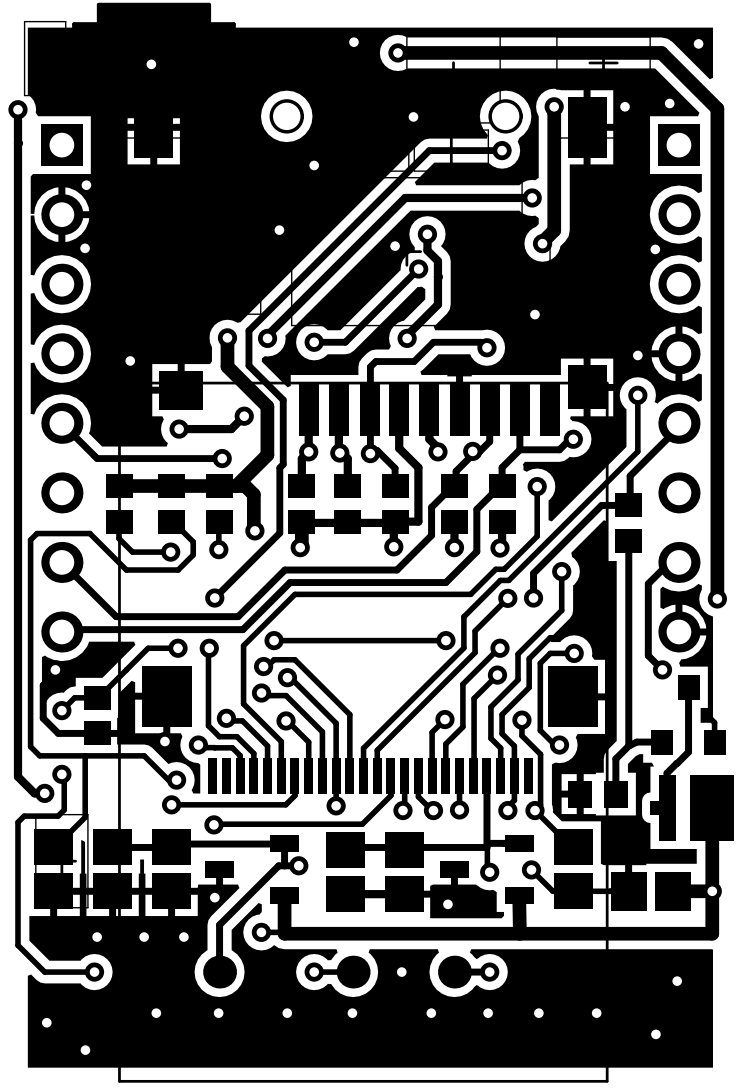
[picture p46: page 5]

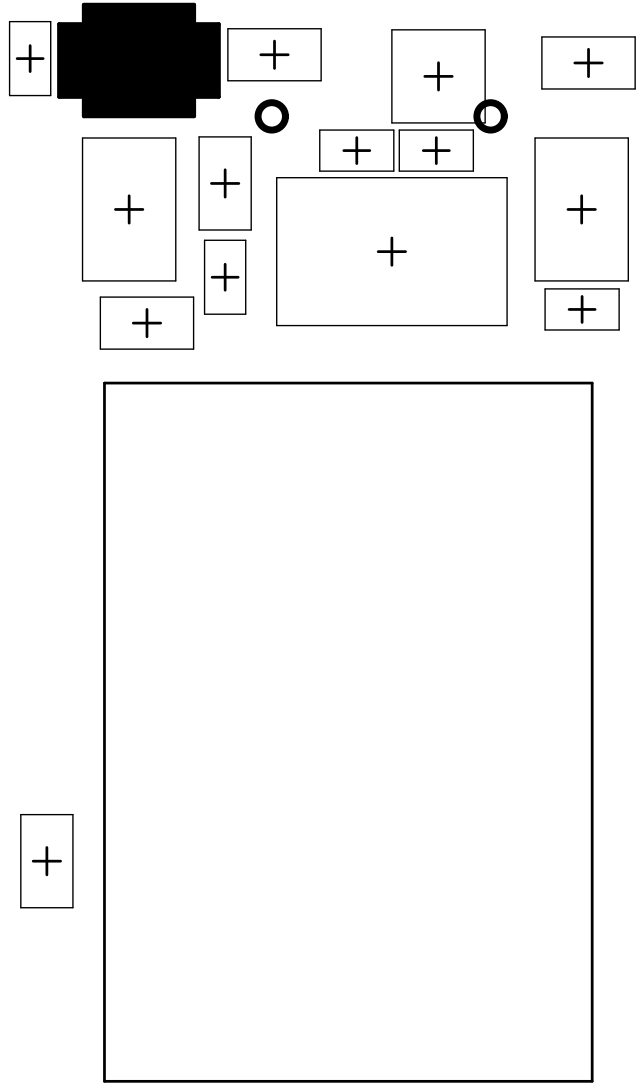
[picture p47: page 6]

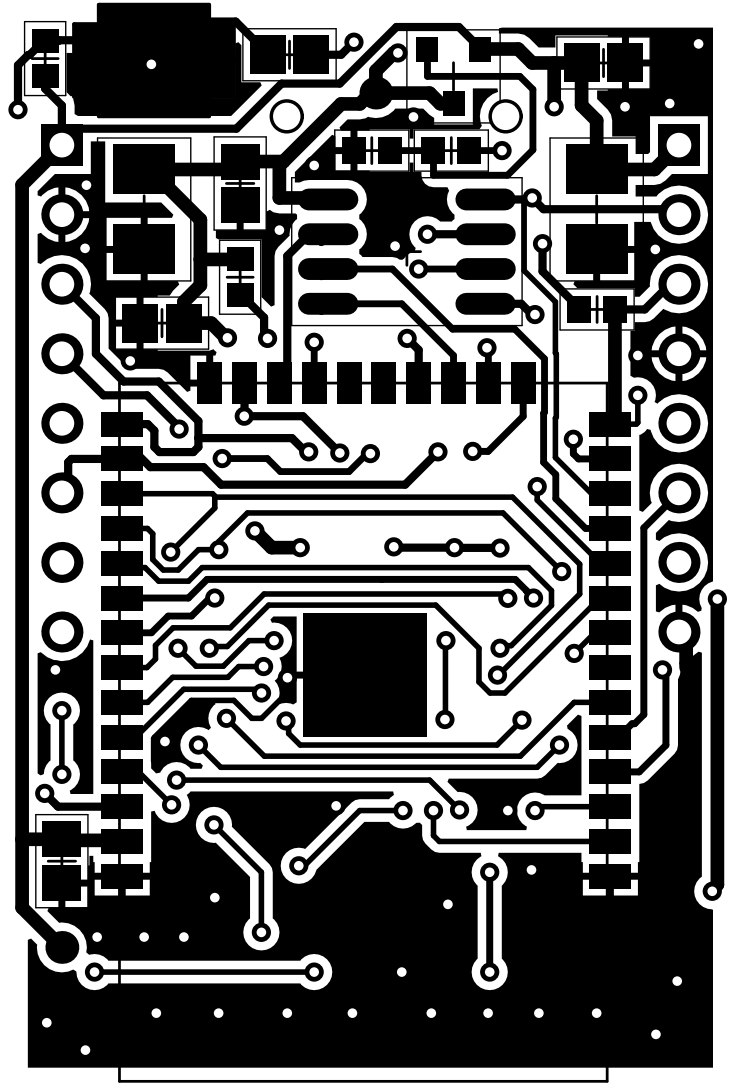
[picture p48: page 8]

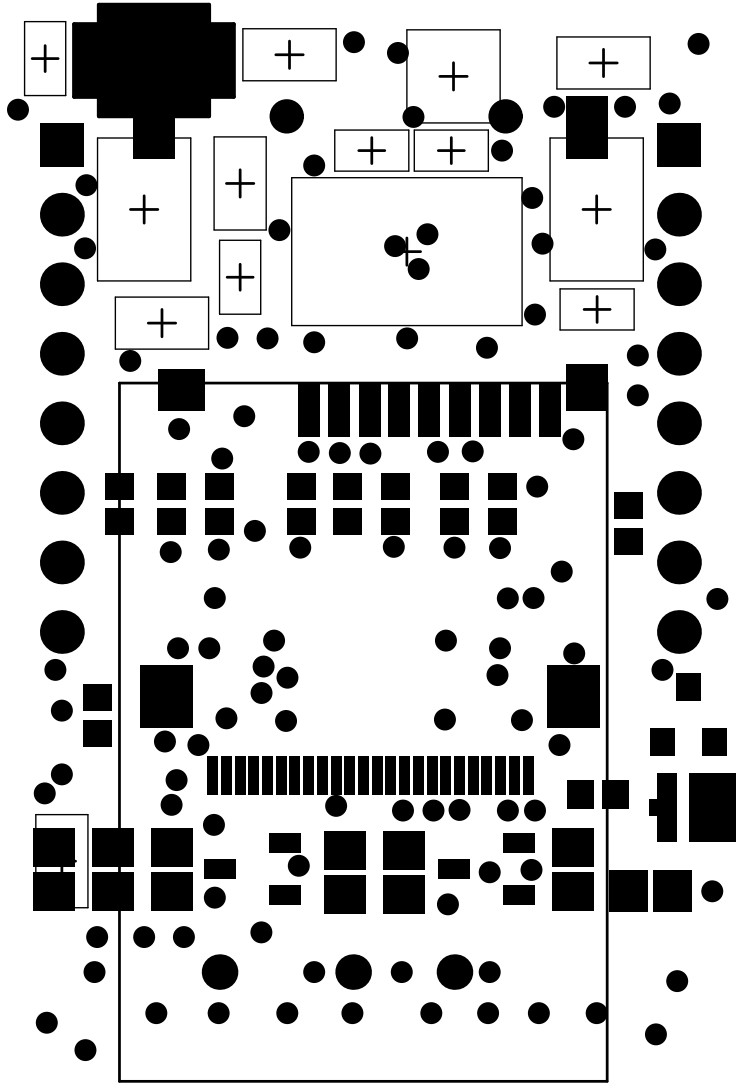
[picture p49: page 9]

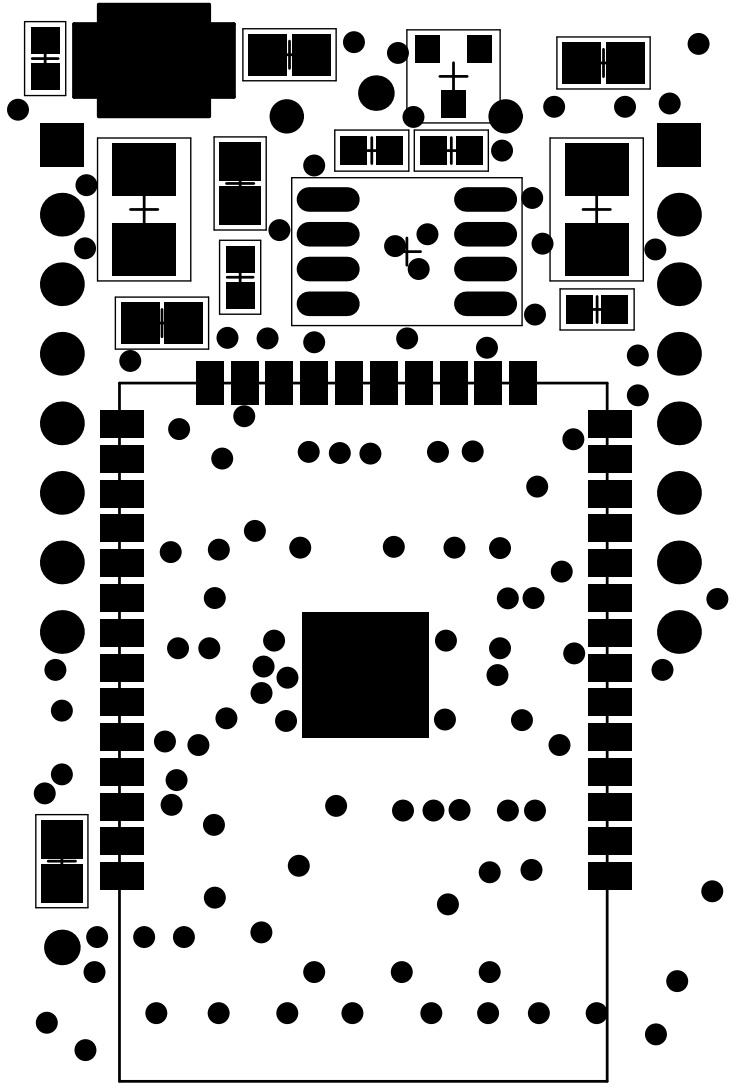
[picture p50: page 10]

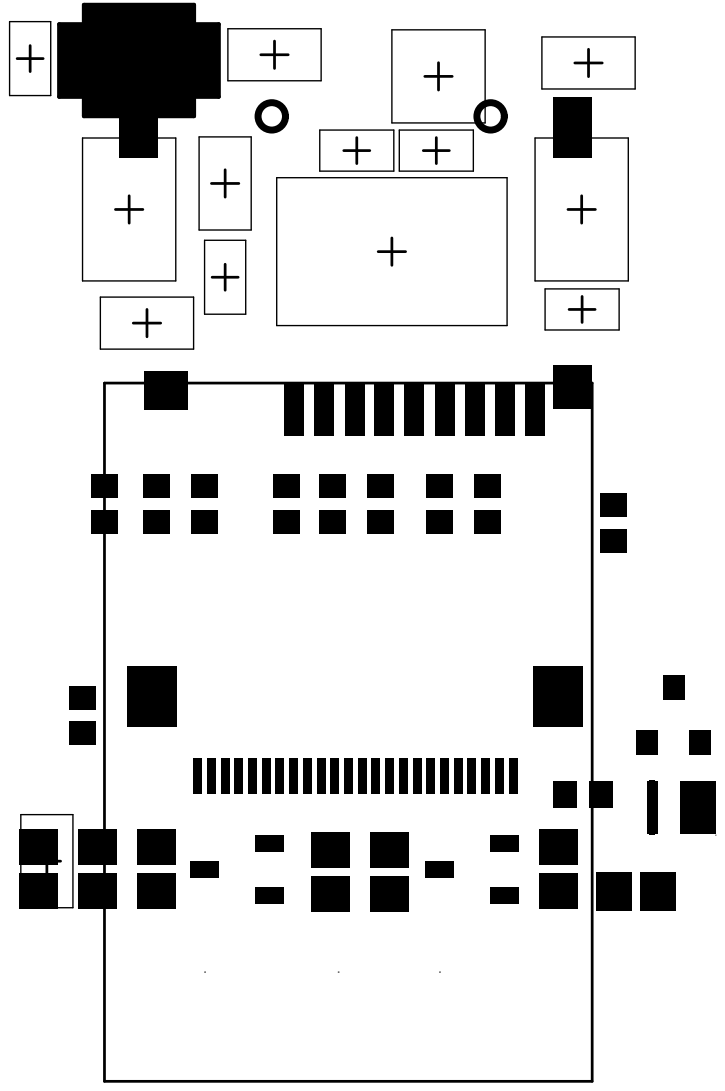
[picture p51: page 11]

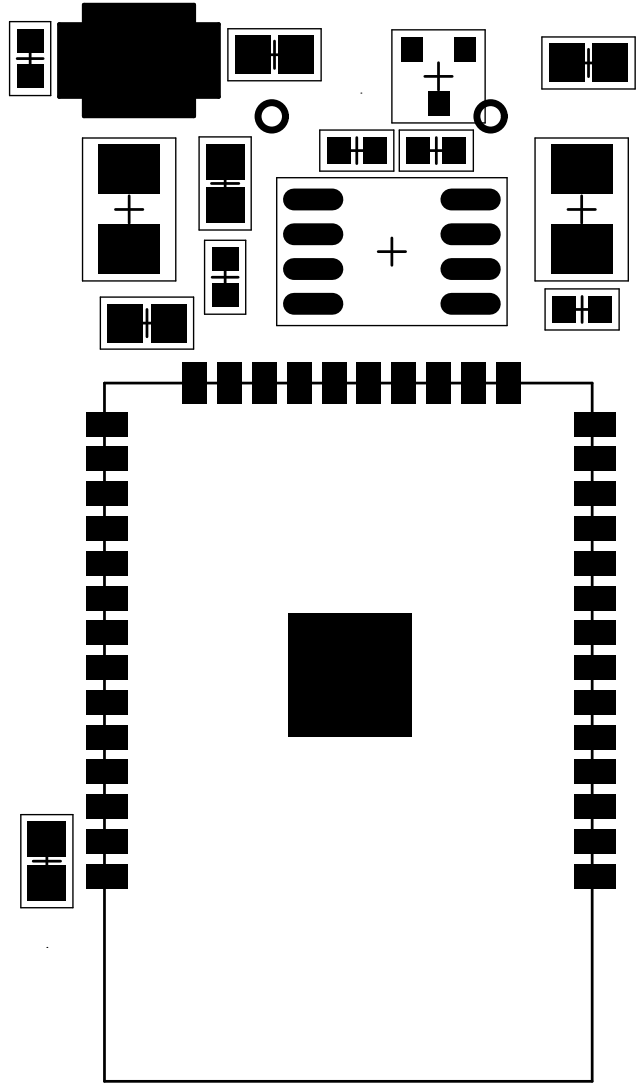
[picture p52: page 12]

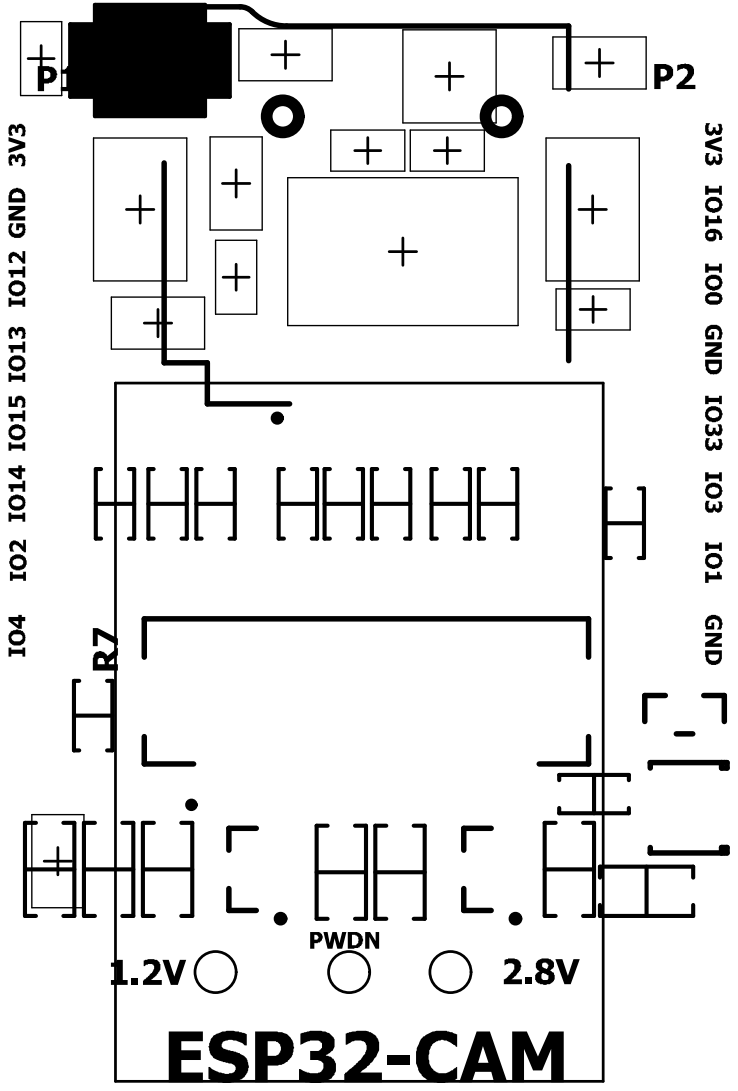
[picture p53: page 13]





Design Rules Verification Report


SMD Entry (Side = Allowed) (Corner = Allowed) (Any Angle = Not Allowed) (Ignore First Corner = Allowed)
SMD Entry Constraint: Between Pad C1-1(2.25mm,9.35mm) on Bottom Layer And Track (2.29mm,9.31mm)(4.41mm,9.31mm) on Bottom Layer Track Entry
SMD Entry Constraint: Between Pad C12-1(8.75mm,34.1mm) on Bottom Layer And Track (5.465mm,33.81mm)(8.46mm,33.81mm) on Bottom Layer Track
SMD Entry Constraint: Between Pad C13-2(6.25mm,9.05mm) on Top Layer And Track (6.288mm,9.175mm)(10.258mm,9.175mm) on Top Layer Track
SMD Entry Constraint: Between Pad C7-2(12.585mm,8.945mm) on Top Layer And Track (12.35mm,9.05mm)(17.75mm,9.05mm) on Top Layer Track Entry
SMD Entry Constraint: Between Pad IC1-10(4.45mm,19.43mm) on Bottom Layer And Track (4.608mm,19.272mm)(5.283mm,19.272mm) on Bottom Layer
SMD Entry Constraint: Between Pad IC1-13(4.45mm,23.24mm) on Bottom Layer And Track (4.937mm,23.476mm)(5.473mm,22.94mm) on Bottom Layer
SMD Entry Constraint: Between Pad IC1-17(10.18mm,26.01mm) on Bottom Layer And Track (10.469mm,26.549mm)(10.469mm,30.654mm) on Bottom
SMD Entry Constraint: Between Pad IC1-2(4.45mm,9.27mm) on Bottom Layer And Track (2.29mm,9.31mm)(4.41mm,9.31mm) on Bottom Layer Track Entry
SMD Entry Constraint: Between Pad IC1-25(22.25mm,24.51mm) on Bottom Layer And Track (22.416mm,24.676mm)(22.416mm,28.699mm) on Bottom
SMD Entry Constraint: Between Pad IC1-31(22.25mm,16.89mm) on Bottom Layer And Track (20.931mm,16.138mm)(21.683mm,16.89mm) on Bottom
SMD Entry Constraint: Between Pad IC1-5(4.45mm,13.08mm) on Bottom Layer And Track (4.696mm,12.834mm)(6.69mm,14.828mm) on Bottom Layer
SMD Entry Constraint: Between Pad IC3-1(18.935mm,7.3mm) on Top Layer And Track (18.925mm,7.3mm)(18.95mm,5.9mm) on Top Layer Track Entry to
SMD Entry Constraint: Between Pad IC4-8(11.96mm,32.715mm) on Bottom Layer And Track (10.18mm,32.77mm)(11.374mm,32.77mm) on Bottom Layer
SMD Entry Constraint: Between Pad IC5-2(10.37mm,9.2mm) on Top Layer And Track (6.288mm,9.175mm)(10.258mm,9.175mm) on Top Layer Track Entry
SMD Entry Constraint: Between Pad J1-20(17.25mm,11.675mm) on Top Layer And Track (17.279mm,11.704mm)(17.279mm,14.492mm) on Top Layer
SMD Entry Constraint: Between Pad R11-1(11mm,20.95mm) on Top Layer And Track (11.047mm,20.903mm)(14.353mm,20.903mm) on Top Layer Track
SMD Entry Constraint: Between Pad R2-1(8mm,20.95mm) on Top Layer And Track (7.973mm,19.927mm)(7.973mm,20.923mm) on Top Layer Track Entry
SMD Entry Constraint: Between Pad R4-1(22.921mm,21.542mm) on Top Layer And Track (22.971mm,21.542mm)(22.971mm,22.617mm) on Top Layer
SMD Entry Constraint: Between Pad R8-1(14.4mm,20.95mm) on Top Layer And Track (11.047mm,20.903mm)(14.353mm,20.903mm) on Top Layer Track
SMD Entry Constraint: Between Pad R8-1(14.4mm,20.95mm) on Top Layer And Track (14.353mm,20.029mm)(14.353mm,20.903mm) on Top Layer Track
SMD Entry Constraint: Between Pad R9-1(16.575mm,20.95mm) on Top Layer And Track (16.565mm,20mm)(16.565mm,20.897mm) on Top Layer Track
SMD Entry Constraint: Between Pad R9-2(16.575mm,22.25mm) on Top Layer And Track (16.625mm,22.25mm)(16.625mm,22.789mm) on Top Layer Track
SMD Entry Constraint: Between Pad TP3-TP?(13.7mm,36.6mm) on Bottom Layer And Track (12.432mm,36.205mm)(13.115mm,36.205mm) on Bottom

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

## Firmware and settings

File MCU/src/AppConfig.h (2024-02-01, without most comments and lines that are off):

#pragma once
#define SD_CARD_ROOT "/sdcard"
#define DEFAULT_LOG_LEVEL_STR "DEBUG"
#define DEFAULT_LOG_FILE_SIZE "1MB"
#define DEFAULT_LOG_FILE_BACKUPS "5"
#define DEFAULT_LOG_FILE_PATH SD_CARD_ROOT "/log"
#define DEFAULT_LOG_FILE_NAME "application.log"
#define LOGGER_MAX_SUBSCRIBERS 3
#define LOGGER_FILE_NAME_MAX_SIZE CONFIG_FATFS_MAX_LFN
#define CONFIG_FILE             SD_CARD_ROOT "/application.properties"
#define WLAN_CONFIG_FILE        SD_CARD_ROOT "/wlan.properties"
#define HTML_TEMPLATE_DIR       SD_CARD_ROOT "/html"
#define HTML_ASSETS_IMAGE_DIR   HTML_TEMPLATE_DIR "/assets/img"
#define CAMERA_IMAGE_DIR        SD_CARD_ROOT "/photo"
#define DATABASE_DIR            SD_CARD_ROOT "/db"
#define EMBEDDED_DATABASE_FILE  DATABASE_DIR "/embedded.db"
#define ENCRYPTION_DIR          SD_CARD_ROOT "/encryption"
#define PRIVATE_KEY_PEM_FILE    ENCRYPTION_DIR "/private_encryption_key.pem"
#define PUBLIC_KEY_PEM_FILE     ENCRYPTION_DIR "/public_encryption_key.pem"
#define HIDE_PASSWORD   // hide password from wlan.properties in log
#define FLASH_GPIO              GPIO_NUM_4
#define BLINK_GPIO              GPIO_NUM_0
#define CONFIG_START_GPIO       GPIO_NUM_0
#define PERIPHERAL_POWER_GPIO   GPIO_NUM_32
#define OLDEST_PHOTOS_TO_REMOVE_COUNT 16
#define DEFAULT_ESP_WIFI_AP_SSID         "AI-Meter-AP"
#define DEFAULT_ESP_WIFI_AP_PASSWORD      ""
#define DEFAULT_ESP_WIFI_AP_CHANNEL       "11"
#define DEFAULT_MAX_STA_CONNECTIONS       "1"
#define CAMERA_MODEL_AI_THINKER
#define BOARD_ESP32CAM_AITHINKER
#define USE_PWM_LED_FLASH
#define CALIBRATION_PHOTO_NAME "calibration_photo.jpeg"
#define CSP_WELCOME_PAGE_NAME "welcome.csp"
#define CSP_CONNECT_PAGE_NAME "connect.csp"
#define CSP_CALIBRATE_PAGE_NAME "calibrate.csp"
#define CSP_SCHEDULE_PAGE_NAME "schedule.csp"
#define CSP_MESSAGING_PAGE_NAME "messaging.csp"
#define CSP_SUMMARY_PAGE_NAME "summary.csp"
#define CSP_ADMIN_PAGE_NAME "admin.csp"
#define CSP_NOT_FOUND_PAGE_NAME "not_found.csp"
#define CSP_MESSAGE_CAPTION_NAME "message_caption.csp"
#define PROPERTY_SYSTEM_FREQUENCY_MHZ_KEY "system.cpu.frequency.mhz"
#define PROPERTY_IP_GEOLOCATION_ENABLED_KEY "ip.geolocation.enabled"
#define PROPERTY_IP_GEOLOCATION_TIMEZONE_FORMAT_URL_KEY "ip.geolocation.timezone.format.url"
#define PROPERTY_IP_GEOLOCATION_API_KEY "ip.geolocation.api.key"
#define PROPERTY_TELEGRAM_API_BOT_NAME_KEY "telegram.api.bot.name"
#define PROPERTY_TELEGRAM_API_URL_KEY "telegram.api.bot.url"
#define PROPERTY_TELEGRAM_API_KEY "telegram.api.bot.api.key"
#define PROPERTY_LOG_LEVEL_KEY "logging.level"
#define PROPERTY_LOG_FILE_PATH_KEY "logging.file.path"
#define PROPERTY_LOG_FILE_NAME_KEY "logging.file.name"
#define PROPERTY_LOG_FILE_ENABLED_KEY "logging.file.enabled"
#define PROPERTY_LOG_CONSOLE_ENABLED_KEY "logging.console.enabled"
#define PROPERTY_LOG_FILE_MAX_SIZE_KEY "logging.file.max.size"
#define PROPERTY_LOG_FILE_MAX_BACKUPS_KEY "logging.file.max.backups"
#define METER_NAME_PREFIX "AI-Meter-"
#define METER_NAME_MAX_LENGTH (62 + sizeof(METER_NAME_PREFIX) - 1)
#define PROPERTY_METER_NAME_KEY "meter.ai.name"
#define PROPERTY_APP_SYSTEM_TIMEZONE_KEY "system.time.zone"
#define PROPERTY_SYSTEM_CRON_EXPR_KEY "system.cron.expr"
#define PROPERTY_ENABLE_CONFIG_KEY "enable.soft.ap.config"
#define PROPERTY_PREVIOUS_CRON_DATE_KEY "system.cron.previous.date" // Format: DATE_TIME_FORMAT_SHORT
#define PROPERTY_WIFI_SSID_KEY "wifi.ssid"
#define PROPERTY_WIFI_PASSWORD_KEY "wifi.password"
#define PROPERTY_WIFI_HOSTNAME_KEY "wifi.hostname"
#define PROPERTY_WIFI_IP_KEY "wifi.ip"
#define PROPERTY_WIFI_GATEWAY_KEY "wifi.gateway"
#define PROPERTY_WIFI_NETMASK_KEY "wifi.netmask"
#define PROPERTY_WIFI_DNS_KEY "wifi.dns"
#define PROPERTY_CALIBRATION_FOTO_KEY "calibration.photo.name"
#define PROPERTY_FLASH_LIGHT_INTENSITY_KEY "flash.light.intensity.level"
#define PROPERTY_TELEGRAM_CHAT_ID_KEY "telegram.chat.id"
#include "FileUtils.h"
#include "Logger.h"
#include "BufferString.h"
#include "GlobalDateTime.h"
#include "CronExpression.h"
#include "SqliteWrapper.h"
#include "BufferVector.h"
#include "Properties.h"
#include "IPAddress.h"
#include "PSRAM.h"
#include "JSON.h"
#include "CSPRenderer.h"
#include "version.h"
extern Properties appConfig;
extern Properties wlanConfig;
extern File imageDirRoot;
extern TimeZone timeZone;
extern CronExpression cron;
extern sqlite3 *embeddedDb;
#define SERVER_FILE_SCRATCH_BUFFER_SIZE (32 * ONE_KB)
#define DATE_TIME_FORMAT_ZONE_STR "yyyy-MM-dd HH:mm:ss ZZZZZ"
#define DATE_TIME_FORMAT_SHORT "yyyy.MM.dd HH:mm"
#define DATE_TIME_FILE_NAME_FORMAT "yyyy_MM_dd_HH_mm"
#define CRON_JOB_ALLOWED_MINUTES_GAP 5
#define SD_CARD_USE_ONE_LINE_MODE
#define CAMERA_CONFIG_FRAMESIZE_UXGA
#if defined(CAMERA_MODEL_WROVER_KIT)
    #define PWDN_GPIO_NUM    -1
    #define RESET_GPIO_NUM   -1
    #define XCLK_GPIO_NUM    21
    #define SIOD_GPIO_NUM    26
    #define SIOC_GPIO_NUM    27
    #define Y9_GPIO_NUM      35
    #define Y8_GPIO_NUM      34
    #define Y7_GPIO_NUM      39
    #define Y6_GPIO_NUM      36
    #define Y5_GPIO_NUM      19
    #define Y4_GPIO_NUM      18
    #define Y3_GPIO_NUM       5
    #define Y2_GPIO_NUM       4
    #define VSYNC_GPIO_NUM   25
    #define HREF_GPIO_NUM    23
    #define PCLK_GPIO_NUM    22
#elif defined(CAMERA_MODEL_M5STACK_PSRAM)
    #define PWDN_GPIO_NUM     -1
    #define RESET_GPIO_NUM    15
    #define XCLK_GPIO_NUM     27
    #define SIOD_GPIO_NUM     25
    #define SIOC_GPIO_NUM     23
    #define Y9_GPIO_NUM       19
    #define Y8_GPIO_NUM       36
    #define Y7_GPIO_NUM       18
    #define Y6_GPIO_NUM       39
    #define Y5_GPIO_NUM        5
    #define Y4_GPIO_NUM       34
    #define Y3_GPIO_NUM       35
    #define Y2_GPIO_NUM       32
    #define VSYNC_GPIO_NUM    22
    #define HREF_GPIO_NUM     26
    #define PCLK_GPIO_NUM     21
#elif defined(CAMERA_MODEL_AI_THINKER)
    #define PWDN_GPIO_NUM     GPIO_NUM_32
    #define RESET_GPIO_NUM    (-1)
    #define XCLK_GPIO_NUM      GPIO_NUM_0
    #define SIOD_GPIO_NUM     GPIO_NUM_26
    #define SIOC_GPIO_NUM     GPIO_NUM_27
    #define Y9_GPIO_NUM       GPIO_NUM_35
    #define Y8_GPIO_NUM       GPIO_NUM_34
    #define Y7_GPIO_NUM       GPIO_NUM_39
    #define Y6_GPIO_NUM       GPIO_NUM_36
    #define Y5_GPIO_NUM       GPIO_NUM_21
    #define Y4_GPIO_NUM       GPIO_NUM_19
    #define Y3_GPIO_NUM       GPIO_NUM_18
    #define Y2_GPIO_NUM        GPIO_NUM_5
    #define VSYNC_GPIO_NUM    GPIO_NUM_25
    #define HREF_GPIO_NUM     GPIO_NUM_23
    #define PCLK_GPIO_NUM     GPIO_NUM_22
#else
    #error "Camera model not selected"
#endif  //camera model
#ifdef BOARD_WROVER_KIT // WROVER-KIT PIN Map
    #define CAM_PIN_PWDN -1  //power down is not used
    #define CAM_PIN_RESET -1 //software reset will be performed
    #define CAM_PIN_XCLK 21
    #define CAM_PIN_SIOD 26
    #define CAM_PIN_SIOC 27
    #define CAM_PIN_D7 35
    #define CAM_PIN_D6 34
    #define CAM_PIN_D5 39
    #define CAM_PIN_D4 36
    #define CAM_PIN_D3 19
    #define CAM_PIN_D2 18
    #define CAM_PIN_D1 5
    #define CAM_PIN_D0 4
    #define CAM_PIN_VSYNC 25
    #define CAM_PIN_HREF 23
    #define CAM_PIN_PCLK 22
#endif //// WROVER-KIT PIN Map
    #define CAM_PIN_PWDN 32
    #define CAM_PIN_RESET (-1) //software reset will be performed
    #define CAM_PIN_XCLK 0
    #define CAM_PIN_SIOD 26
    #define CAM_PIN_SIOC 27
    #define CAM_PIN_D7 35
    #define CAM_PIN_D6 34
    #define CAM_PIN_D5 39
    #define CAM_PIN_D4 36
    #define CAM_PIN_D3 21
    #define CAM_PIN_D2 19
    #define CAM_PIN_D1 18
    #define CAM_PIN_D0 5
    #define CAM_PIN_VSYNC 25
    #define CAM_PIN_HREF 23
    #define CAM_PIN_PCLK 22
#define LEDC_TIMER              LEDC_TIMER_1 // LEDC_TIMER_0
#define LEDC_MODE               LEDC_LOW_SPEED_MODE
#define LEDC_OUTPUT_IO          FLASH_GPIO // Define the output GPIO
#define LEDC_CHANNEL            LEDC_CHANNEL_1
#define LEDC_DUTY_RES           LEDC_TIMER_13_BIT // Set duty resolution to 13 bits
#define LEDC_MAX_DUTY           (8191 / 10)  // Max duty 8191, then divide by 10 for the lowest intensity
#define LEDC_DEFAULT_DUTY       (LEDC_MAX_DUTY / 2) // Set duty to 50%. If max: ((2 ** 13) - 1) * 50% = 4095
#define LEDC_FREQUENCY          (5000) // Frequency in Hertz. Set frequency at 5 kHz
#define LED_RANGE_LEVEL_COUNT   (24)
#define LED_DUTY_PER_LEVEL      (LEDC_MAX_DUTY / LED_RANGE_LEVEL_COUNT)
#define LED_RANGE_LEVELS \
    X(0) X(1) X(2) X(3) X(4) X(5) X(6) X(7) X(8) X(9) X(10) X(11) X(12) \
    X(13) X(14) X(15) X(16) X(17) X(18) X(19) X(20) X(21) X(22) X(23) X(24)
#define BATTERY_ADC_CHANNEL ADC_CHANNEL_6      // GPIO14 -> HS2_CLK will be used one on app startup
#define BATTERY_GPIO_PIN    GPIO_NUM_14
extern void configureButtonWakeup();

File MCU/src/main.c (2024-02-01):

#include "AppConfig.h"

#include "esp_chip_info.h"
#include "esp_flash.h"
#include "freertos/FreeRTOS.h"
#include "freertos/task.h"
#include "sdkconfig.h"
#include <inttypes.h>
#include <stdio.h>

#include "driver/gpio.h"
#include "esp_adc/adc_oneshot.h"
#include "esp_adc/adc_cali.h"
#include "esp_adc/adc_cali_scheme.h"

#include "esp_sleep.h"

#include "SDCard.h"
#include "StatusLed.h"
#include "NTPTime.h"
#include "EspConfig.h"
#include "CameraControl.h"
#include "SoftAPServer.h"
#include "Encryptor.h"

/*
 * Two resistors divider of 100K and 10K
 *
 * Vbat     Vin      GND
 *  |        |        |
 *  +--[R1]--+--[R2]--+
 *
 *  R1 = 100kOhms
 *  R2 = 10kOhms
*/
#define R1 100
#define R2 10
#define VOLTAGE_OUT(Vin) (((Vin) * R2) / (R1 + R2))

// We can take the battery voltage of 4.1V as 100% and the voltage of 3.3V as 0%
#define BATTERY_VOLTAGE_MAX 4100
#define BATTERY_VOLTAGE_MIN 3300

#define BATTERY_DIVIDER_VOLTAGE_MAX (VOLTAGE_OUT(BATTERY_VOLTAGE_MAX))
#define BATTERY_DIVIDER_VOLTAGE_MIN (VOLTAGE_OUT(BATTERY_VOLTAGE_MIN))

static const char *TAG = "MAIN";

Properties appConfig;
Properties wlanConfig;

File imageDirRoot;
CronExpression cron;
sqlite3 *embeddedDb;

static int batteryPercentage;
static DateTimeFormatter photoFileDateTimeFormatter;

static int logOverrideFunction(const char *format, va_list argumentList);
static int getBatteryDividerVoltage();
static bool adcCalibrationInit(adc_unit_t unit, adc_channel_t channel, adc_atten_t atten, adc_cali_handle_t *outHandle);
static void adcCalibrationDeInit(adc_cali_handle_t handle);

static int calculateBatteryPercentage(int dividerVoltage);
static bool initEncryptionModule();
static void executeCronJob();
static void cleanupPhotoDirectory();
static int fileDateCompareFunction (const void *one, const void *two);


void app_main() {

    statusLedOff();

    LoggerEvent *consoleLogger = subscribeConsoleLogger(stringToLogLevel(DEFAULT_LOG_LEVEL_STR));
    if (consoleLogger == NULL) {
        return; // No way to continue without working logger!
    }

    vTaskDelay(pdMS_TO_TICKS(3000));
    int dividerVoltage = getBatteryDividerVoltage();

    LOG_INFO(TAG, "\n================ Start app_main =================");

    gpio_pulldown_en(FLASH_GPIO);   // set pull down to prevent flashlight flickering
    gpio_reset_pin(CONFIG_START_GPIO);

    // Init camera, try several times if no success from the first try
    esp_err_t cameraStatus = initCameraWithRetry(CAMERA_INIT_TRY_COUNT);

    SDCardStatus cardStatus = initNvsSDCard();
    if (cardStatus != SD_CARD_OK) {
        LOG_FATAL(TAG, "SD card init failed!");
        statusLed(SD_CARD_INIT_ERROR, cardStatus, true);
        return;     // No way to continue without working SD card!
    }

    if (checkSDCardRW() != SD_CARD_OK) {
        LOG_FATAL(TAG, "SD card r/w check failed!");
        statusLed(SD_CARD_CHECK_ERROR, cardStatus, true);
        return;     // No way to continue without working SD card!
    }

    Properties *properties = loadProperties(&appConfig, CONFIG_FILE);
    if (properties->status != CONFIG_PROP_OK) {
        LOG_ERROR(TAG, "Filed to load application properties [%s]. Message: [%s]", CONFIG_FILE, propStatusToString(properties->status));
        statusLed(CONFIG_PROP_ERROR, properties->status, true);
        return; // mandatory application properties
    }

    Properties *wlanProperties = loadProperties(&wlanConfig, WLAN_CONFIG_FILE);
    if (wlanProperties->status != CONFIG_PROP_OK) {
        LOG_ERROR(TAG, "Filed to load wlan properties [%s]. Message: [%s]", WLAN_CONFIG_FILE, propStatusToString(wlanProperties->status));
        return; // mandatory wlan properties
    }

    bool isFileLogEnabled = isStringEquals(getPropertyOrDefault(&appConfig, PROPERTY_LOG_FILE_ENABLED_KEY, "false"), "true");
    if (isFileLogEnabled) {
        LOG_INFO(TAG, "File logging enabled. Setup logger from config");
        char *logFilePathStr = getPropertyOrDefault(&appConfig, PROPERTY_LOG_FILE_PATH_KEY, DEFAULT_LOG_FILE_PATH);
        File *logFilePath = NEW_FILE(logFilePathStr);
        File *logFile = FILE_OF(logFilePath, getPropertyOrDefault(&appConfig, PROPERTY_LOG_FILE_NAME_KEY, DEFAULT_LOG_FILE_NAME));
        LOG_INFO(TAG, "Log file path: [%s]", logFile->path);
        createFileDirs(logFile);
        
        char *logLevelStr = getPropertyOrDefault(&appConfig, PROPERTY_LOG_LEVEL_KEY, DEFAULT_LOG_LEVEL_STR);
        LogLevel level = stringToLogLevel(logLevelStr);
        if (level == LOG_LEVEL_UNKNOWN) {
            LOG_ERROR(TAG, "Invalid log level: [%s]. Set default log to: [%s]", logLevelStr, DEFAULT_LOG_LEVEL_STR);
            level = stringToLogLevel(DEFAULT_LOG_LEVEL_STR);
        }

        char *logFileSizeStr = getPropertyOrDefault(&appConfig, PROPERTY_LOG_FILE_MAX_SIZE_KEY, DEFAULT_LOG_FILE_SIZE);
        uint32_t logFileMaxSize = (uint32_t) displaySizeToBytes(logFileSizeStr);
        uint8_t maxBackupFiles = strtol(getPropertyOrDefault(&appConfig, PROPERTY_LOG_FILE_MAX_BACKUPS_KEY, DEFAULT_LOG_FILE_BACKUPS), NULL, 10);
        LoggerEvent *fileLogger = subscribeFileLogger(level, logFile->path, logFileMaxSize, maxBackupFiles);  // Register file logger
        if (!fileLogger->isSubscribed) {
            LOG_FATAL(TAG, "File logger init error: [%s]", fileLogger->buffer);
            statusLed(SD_CARD_CHECK_ERROR, SD_CARD_ERROR_CREATE_FILE, true);
            return;
        }
        esp_log_set_vprintf(logOverrideFunction);   // redirect all logs to custom logger

        bool isConsoleLogEnabled = isStringEquals(getPropertyOrDefault(&appConfig, PROPERTY_LOG_CONSOLE_ENABLED_KEY, "false"), "true");
        if (!isConsoleLogEnabled) {
            LOG_INFO(TAG, "At this point console log will be disabled");
            loggerUnsubscribe(consoleLogger);     // Console logger doesn't need this anymore, all logs will be stored in a log file
        }
        LOG_INFO(TAG, "\nLog file directory: [%s]\n "
                    "File logger level: [%s]\n "
                    "File max size: [%s]\n "
                    "Backup file count: [%d]",
                    logFile->path, 
                    logLevelToString(level), 
                    logFileSizeStr, 
                    maxBackupFiles);
    }

    LOG_INFO(TAG, "Successfully loaded application properties: [%s]. Total values received: [%d]", CONFIG_FILE, propertiesSize(&appConfig));
    logSDCardInformation();
    
    LOG_INFO(TAG, "=================================================");
    LOG_INFO(TAG, "==================== Start ======================");
    LOG_INFO(TAG, "=================================================");

    LOG_INFO("Restart reason: [%s]", getResetReason());
    bool isWakeupButtonPressed = (esp_reset_reason() == ESP_RST_DEEPSLEEP) && (esp_sleep_get_wakeup_cause() == ESP_SLEEP_WAKEUP_EXT0);
    if (isWakeupButtonPressed) {
        LOG_INFO(TAG, "Config GPIO Button was pressed. Enabling Soft AP configuration server");
        putProperty(&wlanConfig, PROPERTY_ENABLE_CONFIG_KEY, "true");
    }
    
    // Set CPU Frequency
    setupEspCpuFrequency();

    esp_err_t psRamStatus = initExternalPSRAM();
    if (psRamStatus != ESP_OK) {
        LOG_FATAL(TAG, "PSRAM init failed");
        statusLed(PSRAM_INIT_ERROR, 1, false);
        return;
    }

    if (cameraStatus != ESP_OK) {
        LOG_FATAL(TAG, "Camera init failed");
        statusLed(CAMERA_INIT_ERROR, 1, false);
        return;
    }

    if (!testCamera()) {    // Camera init OK --> continue to perform camera framebuffer check
        LOG_FATAL(TAG, "Camera framebuffer check failed");
        statusLed(CAMERA_INIT_ERROR, 2, false);
        return;
    }

    sensor_t *sensor = esp_camera_sensor_get();
    LOG_INFO(TAG, "Camera info: PID: 0x%02x, VER: 0x%02x, MIDL: 0x%02x, MIDH: 0x%02x", sensor->id.PID, sensor->id.VER, sensor->id.MIDH, sensor->id.MIDL);
    
    LOG_INFO(TAG,  "\n"
                     "  ___   _____  ___  ___       _                   \n"
                     " / _ \\ |_   _| |  \\/  |      | |                \n"
                     "/ /_\\ \\  | |   | .  . |  ___ | |_   ___  _ __   \n"
                     "|  _  |  | |   | |\\/| | / _ \\| __| / _ \\| '__| \n"
                     "| | | | _| |_  | |  | ||  __/| |_ |  __/| |       \n"
                     "\\_| |_/ \\___/  \\_|  |_/ \\___| \\__| \\___||_| \n"
                     "                                                  \n");

    // Print Device info
    esp_chip_info_t chipInfo;
    esp_chip_info(&chipInfo);
    LOG_INFO(TAG, "Device info: CPU cores: %d, Chip revision: %d", chipInfo.cores, chipInfo.revision);

    TickType_t xDelay = 2000;
    LOG_DEBUG(TAG, "main: sleep for: %d ms", xDelay);
    vTaskDelay(pdMS_TO_TICKS(xDelay));

    batteryPercentage = calculateBatteryPercentage(dividerVoltage);

    bool isRsaKeysLoaded = initEncryptionModule();  // Load and initialize encryption keys
    if (!isRsaKeysLoaded) {
        LOG_ERROR(TAG, "RSA key generate/load fail. Deleting PEM key files and clean encrypted data");
        File *encryptionDir = NEW_FILE(ENCRYPTION_DIR);
        deleteDirectory(encryptionDir);
        LOG_INFO(TAG, "Restarting device to reconfigure");
        esp_restart();
    }

    newFile(&imageDirRoot, CAMERA_IMAGE_DIR);
    MKDIR(imageDirRoot.path);

    initWifiMain();     // base wi-fi configuration
    initRestClient();   // base rest client

    embeddedDb = sqliteDbInit(EMBEDDED_DATABASE_FILE);
    if (embeddedDb == NULL) {
        LOG_ERROR(TAG, "Error open DB initialization: [%s]", EMBEDDED_DATABASE_FILE);
        return; // DB is mandatory to the application
    }
    LOG_INFO(TAG, "DB successfully initialized: [%s]", EMBEDDED_DATABASE_FILE);

    setupUserTimeZone();    // resolve timezone from config if present

    if (wifiHasLogAndPassToConnect(&wlanConfig)) {  // try to connect if credentials already provided
        LOG_DEBUG(TAG, "Wifi credentials provided, connecting to wifi");
        uint8_t i = 0;
        do {
            if (wifiInitSta(&wlanConfig) == ESP_OK) break;
            i++;
        } while (!isWifiHasConnection() && i < 3);

        if (isWifiHasConnection()) {
            setupNtpTime(); // init ntp time, we have connection already
            if (!isProjectTimeSet()) {
                LOG_ERROR(TAG, "Time is not configured, retry after restart");
                esp_restart();
            }

            loadTimezoneHistoricRules(&timeZone);   // at this point time should be setup, then load DST rules
            LOG_INFO(TAG, "Time now corrected to DST rules: [%s]", getCurrentTimeString(DATE_TIME_FORMAT_ZONE_STR));
        }
    }

    if (!isAppFullyConfigured(&wlanConfig) || isWakeupButtonPressed || !isWifiHasConnection()) { // Not configured or button pressed, then enable soft AP server
        LOG_INFO(TAG, "Starting access point for remote configuration");
        wifiInitSoftAp(&appConfig);
        startWebServerAP();
        // TODO: Uncomment this with updated board design
//        statusLed(AP_OR_OTA_ENABLED, 2, true);
        while(true) { // wait until reboot
            vTaskDelay(pdMS_TO_TICKS(1000));
        }
    }
    LOG_INFO(TAG, "Project fully configured, enabling worker mode");

    char *cronStr = getProperty(&wlanConfig, PROPERTY_SYSTEM_CRON_EXPR_KEY);
    CronStatus cronStatus = parseCronExpression(&cron, cronStr);
    if (cronStatus == CRON_OK) {
        LOG_INFO(TAG, "Cron initialized OK!");
    }

    executeCronJob();   // send a meter photo with data if it is time
    statusLedOff();
    cleanupPhotoDirectory();    // remove old photos
    configureButtonWakeup();    // if button pressed, then need to reconfigure app settings, wakeup from sleep and start soft AP server
    enterTimerDeepSleep(calculateSecondsToWaitFromNow());
}

void configureButtonWakeup() {
    gpio_config_t ioConfig;
    ioConfig.intr_type = GPIO_PIN_INTR_DISABLE; // Disable interrupt on GPIO
    ioConfig.pin_bit_mask = (1ULL << CONFIG_START_GPIO);
    ioConfig.mode = GPIO_MODE_INPUT_OUTPUT;
    ioConfig.pull_up_en = GPIO_PULLUP_DISABLE;
    ioConfig.pull_down_en = GPIO_PULLDOWN_ENABLE;
    gpio_config(&ioConfig);

    gpio_pulldown_en(CONFIG_START_GPIO);
    esp_sleep_enable_ext0_wakeup(CONFIG_START_GPIO, 1); // 1 for high-level wakeup
}

static int logOverrideFunction(const char *format, va_list argumentList) {
    static char buffer[LOGGER_BUFFER_SIZE] = {0};
    vsprintf(buffer, format, argumentList);
    LOG_TRACE(TAG, trimString(buffer));
    return vprintf(format, argumentList); // ALWAYS Write to stdout
}

static int getBatteryDividerVoltage() {
    LOG_DEBUG(TAG, "-------------ADC2 Init---------------");
    adc_oneshot_unit_handle_t adc2Handle;
    adc_oneshot_unit_init_cfg_t initConfig = {
            .unit_id = ADC_UNIT_2,
            .ulp_mode = ADC_ULP_MODE_DISABLE,
    };
    ESP_ERROR_CHECK(adc_oneshot_new_unit(&initConfig, &adc2Handle));

    LOG_DEBUG(TAG, "-------------ADC2 Calibration Init---------------");
    adc_cali_handle_t adc2CalibrationHandle = NULL;
    bool isDoCalibration = adcCalibrationInit(ADC_UNIT_2, BATTERY_ADC_CHANNEL, ADC_ATTEN_DB_11, &adc2CalibrationHandle);

    LOG_DEBUG(TAG, "-------------ADC2 Config---------------");
    adc_oneshot_chan_cfg_t config = {
            .bitwidth = ADC_BITWIDTH_DEFAULT,
            .atten = ADC_ATTEN_DB_11,
    };
    ESP_ERROR_CHECK(adc_oneshot_config_channel(adc2Handle, BATTERY_ADC_CHANNEL, &config));

    LOG_DEBUG(TAG, "-------------ADC2 Read---------------");
    int outRaw = 0;
    int voltage = 0;

    ESP_ERROR_CHECK(adc_oneshot_read(adc2Handle, BATTERY_ADC_CHANNEL, &outRaw));
    LOG_INFO(TAG, "ADC%d Channel[%d] Raw Data: %d", ADC_UNIT_2 + 1, BATTERY_ADC_CHANNEL, outRaw);
    if (isDoCalibration) {
        ESP_ERROR_CHECK(adc_cali_raw_to_voltage(adc2CalibrationHandle, outRaw, &voltage));
        LOG_INFO(TAG, "ADC%d Channel[%d] Calibration Voltage: %d mV", ADC_UNIT_2 + 1, BATTERY_ADC_CHANNEL, voltage);
    }

    //Tear Down
    ESP_ERROR_CHECK(adc_oneshot_del_unit(adc2Handle));
    if (isDoCalibration) {
        adcCalibrationDeInit(adc2CalibrationHandle);
    }
    gpio_reset_pin(BATTERY_GPIO_PIN);
    return voltage;
}

static bool adcCalibrationInit(adc_unit_t unit, adc_channel_t channel, adc_atten_t atten, adc_cali_handle_t *outHandle) {
    adc_cali_handle_t handle = NULL;
    esp_err_t ret = ESP_FAIL;
    bool calibrated = false;

#if ADC_CALI_SCHEME_CURVE_FITTING_SUPPORTED
    if (!calibrated) {
        LOG_INFO(TAG, "Calibration scheme version is [%s]", "Curve Fitting");
        adc_cali_curve_fitting_config_t cali_config = {
            .unit_id = unit,
            .chan = channel,
            .atten = atten,
            .bitwidth = ADC_BITWIDTH_DEFAULT,
        };
        ret = adc_cali_create_scheme_curve_fitting(&cali_config, &handle);
        if (ret == ESP_OK) {
            calibrated = true;
        }
    }
#endif

#if ADC_CALI_SCHEME_LINE_FITTING_SUPPORTED
    if (!calibrated) {
        ESP_LOGI(TAG, "Calibration scheme version is [%s]", "Line Fitting");
        adc_cali_line_fitting_config_t cali_config = {
            .unit_id = unit,
            .atten = atten,
            .bitwidth = ADC_BITWIDTH_DEFAULT,
        };
        ret = adc_cali_create_scheme_line_fitting(&cali_config, &handle);
        if (ret == ESP_OK) {
            calibrated = true;
        }
    }
#endif

    *outHandle = handle;
    if (ret == ESP_OK) {
        LOG_INFO(TAG, "Calibration Success");
    } else if (ret == ESP_ERR_NOT_SUPPORTED || !calibrated) {
        LOG_WARN(TAG, "eFuse not burnt, skip software calibration");
    } else {
        LOG_ERROR(TAG, "Invalid ADC arg or no memory");
    }

    return calibrated;
}

static void adcCalibrationDeInit(adc_cali_handle_t handle) {
#if ADC_CALI_SCHEME_CURVE_FITTING_SUPPORTED
    LOG_INFO(TAG, "Deregister [%s] calibration scheme", "Curve Fitting");
    ESP_ERROR_CHECK(adc_cali_delete_scheme_curve_fitting(handle));

#elif ADC_CALI_SCHEME_LINE_FITTING_SUPPORTED
    LOG_INFO(TAG, "Deregister [%s] calibration scheme", "Line Fitting");
    ESP_ERROR_CHECK(adc_cali_delete_scheme_line_fitting(handle));
#endif
}

static int calculateBatteryPercentage(int dividerVoltage) {
    int battPercentage = 100 * (dividerVoltage - BATTERY_DIVIDER_VOLTAGE_MIN) / (BATTERY_DIVIDER_VOLTAGE_MAX - BATTERY_DIVIDER_VOLTAGE_MIN);
    LOG_INFO(TAG, "Battery divider voltage: [%d], Percentage: [%d%%]", dividerVoltage, battPercentage);

    if (battPercentage < 0) {
        return 0;
    } else if (battPercentage > 100) {
        return 100;
    } else {
        return battPercentage;
    }
}

static bool initEncryptionModule() {
    File *privateRsaKeyFile = NEW_FILE(PRIVATE_KEY_PEM_FILE);
    File *publicRsaKeyFile = NEW_FILE(PUBLIC_KEY_PEM_FILE);

    bool isRsaKeyGenerated = true;
    if (!isFileExists(privateRsaKeyFile) || !isFileExists(publicRsaKeyFile)) {
        MKDIR(ENCRYPTION_DIR);
        createFile(privateRsaKeyFile);
        createFile(publicRsaKeyFile);
        isRsaKeyGenerated = generateRsaKeyPair(publicRsaKeyFile, privateRsaKeyFile);
    }
    return isRsaKeyGenerated ? loadRsaEncryptionKeys(publicRsaKeyFile, privateRsaKeyFile) : false;
}

static void executeCronJob() {
    LOG_INFO(TAG, "Cron job started!");
    ZonedDateTime zdtNow = zonedDateTimeNow(&timeZone);
    LOG_INFO(TAG, "Cron now: %s", zonedDateTimeToStrByFormat(&zdtNow, DATE_TIME_FORMAT_SHORT));

    char *previousExecutionDateStr = getProperty(&wlanConfig, PROPERTY_PREVIOUS_CRON_DATE_KEY);
    DateTimeFormatter formatter;
    parseDateTimePattern(&formatter, DATE_TIME_FORMAT_SHORT);
    DateTime previousDateTime = parseToDateTime(previousExecutionDateStr, &formatter);
    ZonedDateTime previousZdt = zonedDateTimeOfDateTime(&previousDateTime, &timeZone);

    ZonedDateTime expectedExecution = nextCronZonedDateTime(&cron, &previousZdt);
    LOG_INFO(TAG, "Cron expected execution: %s", zonedDateTimeToStrByFormat(&expectedExecution, DATE_TIME_FORMAT_SHORT));
    ZonedDateTime *before = zonedDateTimeMinusMinutes(&Z_DATE_TIME_COPY(expectedExecution), CRON_JOB_ALLOWED_MINUTES_GAP + 1);
    ZonedDateTime *after = zonedDateTimePlusMinutes(&Z_DATE_TIME_COPY(expectedExecution), CRON_JOB_ALLOWED_MINUTES_GAP + 1);

    if (isDateTimeBetween(&zdtNow.dateTime, &before->dateTime, &after->dateTime)) {
        LOG_INFO(TAG, "Cron job approved. Starting task execution...");
        char *ledDutyStr = getProperty(&wlanConfig, PROPERTY_FLASH_LIGHT_INTENSITY_KEY);
        int64_t ledDuty;
        cStrToInt64(ledDutyStr, &ledDuty, 10);
        setLedIntensity((int32_t) ledDuty);

        BufferString *imageFileName = STRING_FORMAT_64("photo_%s.jpeg", zonedDateTimeToStrByFormat(&zdtNow, DATE_TIME_FILE_NAME_FORMAT));
        cameraCaptureToFile(imageFileName->value);
        File *imageFile = FILE_OF(&imageDirRoot, imageFileName->value);

        CspTemplate *messageTemplate = newCspTemplate(HTML_TEMPLATE_DIR "/" CSP_MESSAGE_CAPTION_NAME);
        logTemplate(messageTemplate, CSP_MESSAGE_CAPTION_NAME);

        CspObjectMap *params = newCspParamObjMap(8);
        cspAddStrToMap(params, "meterName", getProperty(&wlanConfig, PROPERTY_METER_NAME_KEY));
        cspAddStrToMap(params, "meterReadings", NULL);
        cspAddIntToMap(params, "battery", batteryPercentage);
        cspAddStrToMap(params, "date", zonedDateTimeToStrByFormat(&zdtNow, DATE_TIME_FORMAT_SHORT));

        CspRenderer *renderer = NEW_CSP_RENDERER(messageTemplate, params);
        CspTableString *captionMessage = renderCspTemplate(renderer);
        sendTelegramPhotoWithCaption(imageFile, captionMessage->value, captionMessage->length);

        deleteCspRenderer(renderer);
        deleteCspTemplate(messageTemplate);

        // End time should be over max gap, its guarantee that photo will not be sent twice or more when a device powered just in a time gap, or wakeup seconds calculated incorrectly
        ZonedDateTime *jobEndDateTime = zonedDateTimePlusMinutes(after, 1);
        putProperty(&wlanConfig, PROPERTY_PREVIOUS_CRON_DATE_KEY, zonedDateTimeToStrByFormat(jobEndDateTime, DATE_TIME_FORMAT_SHORT));
        storeProperties(&wlanConfig, WLAN_CONFIG_FILE);
        LOG_INFO(TAG, "Cron job finished");
        return;
    }

    putProperty(&wlanConfig, PROPERTY_PREVIOUS_CRON_DATE_KEY, zonedDateTimeToStrByFormat(&zdtNow, DATE_TIME_FORMAT_SHORT));
    storeProperties(&wlanConfig, WLAN_CONFIG_FILE);
    LOG_INFO(TAG, "Cron end");
}

static void cleanupPhotoDirectory() {
    File *fileBuffer = callocPsramHeap(MAX_FILES_IN_DIR + 1, sizeof(struct File));
    fileVector *photoVec = NEW_VECTOR_BUFF(File, file, fileBuffer, MAX_FILES_IN_DIR + 1);
    listFiles(&imageDirRoot, photoVec, false);

    LOG_INFO(TAG, "Total photos in dir: [%d]", fileVecSize(photoVec));
    if (fileVecSize(photoVec) >= MAX_FILES_IN_DIR) {
        LOG_INFO(TAG, "Collected photos more than: %d. Removing oldest %d photos", MAX_FILES_IN_DIR, OLDEST_PHOTOS_TO_REMOVE_COUNT);
        parseDateTimePattern(&photoFileDateTimeFormatter, DATE_TIME_FILE_NAME_FORMAT);
        qsort(photoVec->items, fileVecSize(photoVec), sizeof(File), fileDateCompareFunction);   // sort by photo date time from it name, first will be the oldest one

        for (int i = 0; i < OLDEST_PHOTOS_TO_REMOVE_COUNT; i++) { // remove oldest 20 photos
            File fileToRemove = fileVecGet(photoVec, i);
            remove(fileToRemove.path);    // calibration photo will be in the list bottom, so it will not be deleted
        }
    }
    freePsramHeap(fileBuffer);
}
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

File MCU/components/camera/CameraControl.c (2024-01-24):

#include "CameraControl.h"

#ifndef MAX
#define MAX(a,b) ((a) > (b) ? (a) : (b))
#endif

#ifndef MIN
#define MIN(a,b) ((a) < (b) ? (a) : (b))
#endif

static const char *TAG = "CAM";

static int32_t ledIntensity = LEDC_DEFAULT_DUTY;
static bool isCameraInitSuccessfull = false;


static camera_config_t cameraConfig = {
    .pin_pwdn = CAM_PIN_PWDN,
    .pin_reset = CAM_PIN_RESET,
    .pin_xclk = CAM_PIN_XCLK,
    .pin_sccb_sda = CAM_PIN_SIOD,
    .pin_sccb_scl = CAM_PIN_SIOC,

    .pin_d7 = CAM_PIN_D7,
    .pin_d6 = CAM_PIN_D6,
    .pin_d5 = CAM_PIN_D5,
    .pin_d4 = CAM_PIN_D4,
    .pin_d3 = CAM_PIN_D3,
    .pin_d2 = CAM_PIN_D2,
    .pin_d1 = CAM_PIN_D1,
    .pin_d0 = CAM_PIN_D0,
    .pin_vsync = CAM_PIN_VSYNC,
    .pin_href = CAM_PIN_HREF,
    .pin_pclk = CAM_PIN_PCLK,

    //XCLK 20MHz or 10MHz for OV2640 double FPS (Experimental)
    .xclk_freq_hz = 10000000,             // Orginal value
    .ledc_timer = LEDC_TIMER_0,
    .ledc_channel = LEDC_CHANNEL_0,

    .pixel_format = PIXFORMAT_JPEG,     // YUV422,GRAYSCALE,RGB565,JPEG
    .frame_size = FRAME_SIZE,           // QQVGA-UXGA Do not use sizes above QVGA when not JPEG
    .jpeg_quality = 10,                 // 0-63 lower number means higher quality
    .fb_count = 2,                      // if more than one, i2s runs in continuous mode. Use only with JPEG
    .fb_location = CAMERA_FB_IN_PSRAM, // The location where the frame buffer will be allocated */
    .grab_mode = CAMERA_GRAB_LATEST,   // only from new esp32cam version
};
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

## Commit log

2023-12-13 Initial project files
    [AI_Meter_Holder.3mf, Assembly.SLDASM, Base.SLDPRT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]
2023-12-18 Readme template. NPE fix for an invalid key. Psram buffer for photo list
    [Assembly.SLDASM, Base.SLDPRT, Holder.SLDPRT]
2023-12-20 Readme, images, fixes
    [Bill of Materials-esp32-cam-shield.xls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]
2023-12-26 Readme update. Assembly part 1
    [AI_Meter_Holder.3mf, Assembly.SLDASM, Base.SLDPRT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]
2024-01-04 Readme update. Fix for code and models
    [Assembly.SLDASM, Base.SLDPRT, Bill of Materials-esp32-cam-shield.xls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]
2024-01-06 Esp32 cam custom board design
    [PCB.PcbDoc, PCBLib.PcbLib, PCB_Project.PrjPcb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]
2024-01-24 Esp32 cam custom board project impl. Admin properties view fetch from a map, not from file.
    [Bill of Materials-esp32-cam-shield.xls, Bill of Materials-esp32-cam.xls, PCB - CONNECTOR - GCT - GCT FFC2B28-24.PCBLIB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]
